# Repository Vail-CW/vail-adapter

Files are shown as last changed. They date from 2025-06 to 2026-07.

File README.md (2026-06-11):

# Vail Adapter: Morse Code Key / Paddle to USB

<p align="center">
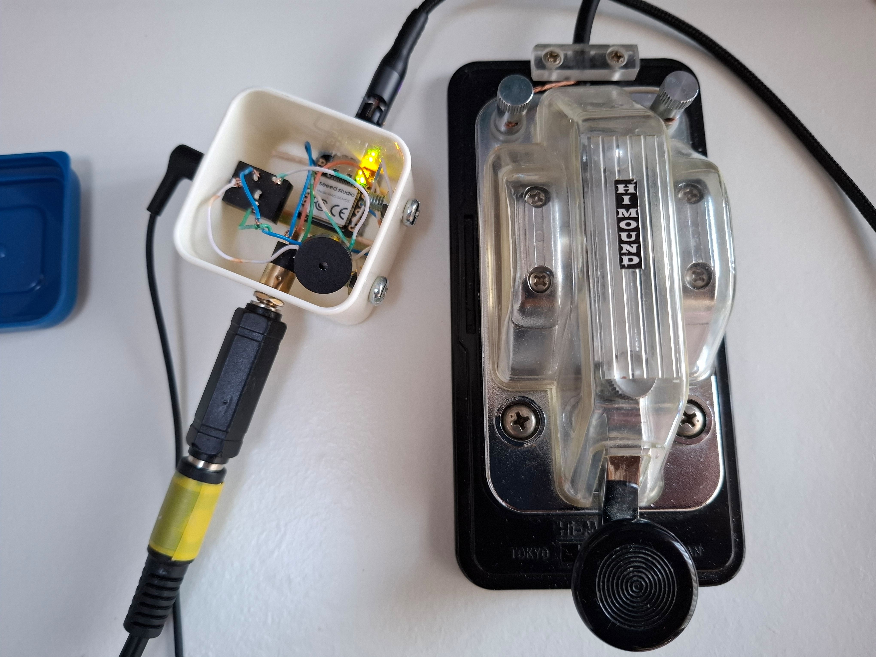
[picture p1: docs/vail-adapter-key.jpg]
Vail Adapter wired to a straight key
  
  &nbsp;&nbsp;
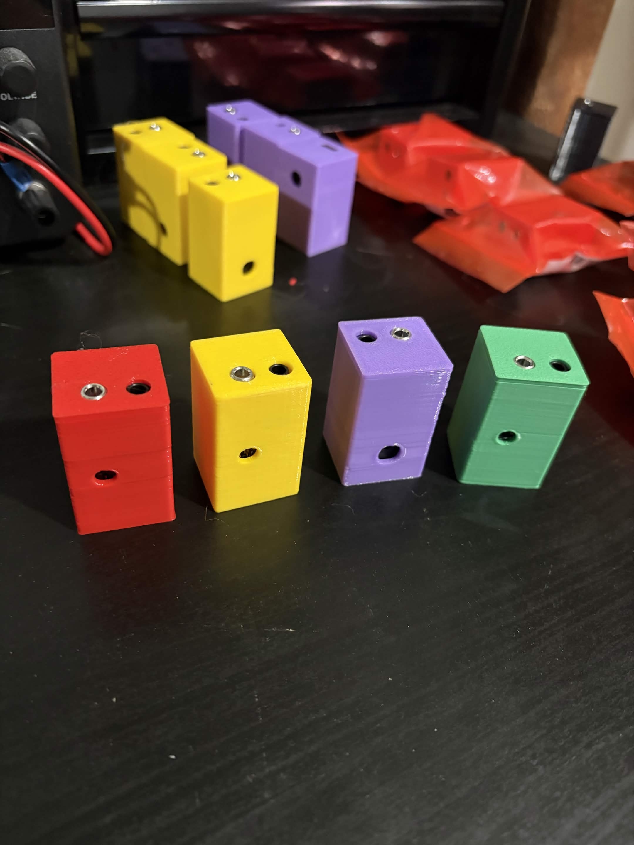
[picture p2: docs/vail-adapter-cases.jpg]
Vail Adapter 3D printed cases in several colors
  
</p>

The Vail Adapter is a small USB gadget that turns your Morse key or paddle into a USB device. It shows up as both a keyboard and a MIDI device, so it works with [Vail](https://vail.woozle.org/), [VBand](https://hamradio.solutions/vband/), and pretty much any CW software. The keyer logic and the sidetone run on the adapter itself, so there is no browser or operating system latency in your keying, even when you are running fast. It works on SAMD21 boards (the Seeed XIAO, the Adafruit QT Py, and the TRRS Trinkey), and there is an experimental build for the AVR Arduino Micro.

Here is a short video that shows what it can do: [Vail Adapter benefits](https://www.youtube.com/watch?v=XQ-mwdyLkOY) (4:46).

## What it does

* With Vail you can keep keying even when the Vail window is not focused, because Vail uses MIDI and MIDI does not care which window has focus
* Keyboard based apps like VBand work too, but their window has to stay focused, since keyboard presses only reach the window that is focused
* Runs all nine Vail keyer modes on the adapter, so you can key as fast as you want with no latency
* Has an optional sidetone generator, which helps with latency and lets you turn off your computer speaker
* Plays the received signal on the adapter so you can keep the computer quiet
* Stores CW memories: three slots, about 25 seconds each on SAMD21, and about 12 seconds each on the Arduino Micro
* Can key a radio directly through the optional radio output on the Advanced PCB
* Can be set up over MIDI for speed, tone, keyer type, and mode (see [MIDI integration](#midi-integration))
* Gets free firmware updates for life

## Where to get one

If you would rather not build your own, I sell them at [shop.ke9bos.com](https://shop.ke9bos.com). You can get a bare PCB, a full kit with everything you need, or a finished unit that is ready to plug in.

If you want to special order parts, place a bulk order, or you have a question about anything Vail related, email me at ke9bos@pigletradio.org and I will take care of you.

## Updating the firmware

You can flash the latest firmware right from your browser (Chrome, Edge, or Opera) at [update.vailadapter.com](https://update.vailadapter.com). Choose your board, pick a version, and follow the steps on the page. Every firmware version is posted on the [releases page](https://github.com/Vail-CW/vail-adapter/releases).

## First time setup

Once you have flashed an adapter, the first thing to do is run the getting started tool at [vailadapter.com/gettingstarted](https://vailadapter.com/gettingstarted). It walks you through getting set up and making sure everything is working.

The full manual is on the website at [vailadapter.com/manual](https://vailadapter.com/manual). It covers the buttons, the keyer modes, the memories, and the rest of the day to day use.

## Building your own

Step by step assembly guides for both boards are on the website at [vailadapter.com/assembly](https://vailadapter.com/assembly), and the PDFs are kept in this repo too: [Basic PCB v2](online-updater/assembly/BasicPCBV2.pdf) and [Advanced](online-updater/assembly/AdvancedAdapterAssemblyInstructions.pdf). If you would rather not source parts and solder, you can get a kit or a finished unit from [shop.ke9bos.com](https://shop.ke9bos.com).

The board designs (KiCad and gerbers) and the printable cases are in [hardware/](hardware/), organized by variant.

### Basic PCB (v2)

* Seeed Studio XIAO SAMD21 (from [Amazon](https://www.amazon.com/gp/product/B08CN5YSQF?smid=A2OY3Y9CEYQQ5W)) or an [Adafruit QT Py SAMD21](https://www.adafruit.com/product/4600)
* A buzzer speaker
* A [PCB mount TRS connector](https://a.co/d/bLaRwym)
* A [switched PCB mount aux jack](https://www.amazon.com/dp/B07WR748JS)

You can order the bare PCB from JLCPCB or PCBWAY yourself, or get a bare board, a kit, or an assembled unit from [shop.ke9bos.com](https://shop.ke9bos.com).

### Advanced PCB

The Advanced PCB does everything the Basic does and adds a radio output, so you can key a rig directly, along with capacitive touch points. It uses more parts than the Basic build:

* Seeed Studio XIAO SAMD21 or an Adafruit QT Py SAMD21
* A buzzer speaker
* The Advanced Vail Adapter PCB
* 1 switching aux jack and 2 standard aux jacks
* 2 transistors and 2 resistors, which drive the radio output
* 2 screw terminal PCB mounts
* 2 headers for the Arduino

The radio output parts are easy to get wrong when you buy them one at a time, so most people get the Advanced build as a kit or assembled from [shop.ke9bos.com](https://shop.ke9bos.com). The full build steps are in the [Advanced assembly guide](online-updater/assembly/AdvancedAdapterAssemblyInstructions.pdf).

### Without a PCB

* Seeed Studio XIAO SAMD21 (or an Adafruit QT Py SAMD21)
* A buzzer speaker
* A [panel mount aux jack](https://www.amazon.com/dp/B01C3RFHDC)

### Vail Lite, the USB stick version

* An [Adafruit TRRS Trinkey M0](https://www.adafruit.com/product/5954), which is a USB stick sized board with a TRRS jack built in
* A piezo buzzer, connected through the STEMMA QT connector
* It has no buttons, no capacitive touch, no headphone jack, and no radio output, so you change settings over MIDI
* Full instructions are in [TRRS_TRINKEY_BUILD.md](docs/TRRS_TRINKEY_BUILD.md)

### Arduino Micro (experimental)

This is a 5V AVR alternative to the SAMD21 boards. It is for DIY and breadboard builds only, and there is no PCB made for it.

* Wiring: D2 is Dit, D1 is Dah, D0 is the Straight Key, D10 is the Piezo, and GND is ground. There is a full walkthrough in [docs/advanced-install.md](docs/advanced-install.md).
* A few things it cannot do compared to the SAMD21 boards: no capacitive touch, no button menu, and no status LEDs. The CW memories are shorter at about 12 seconds each, and the radio output on A2 and A3 runs at 5V, so check that your radio can handle it or use a level shifter.
* Flashing is different too. It uses WebSerial with the AVR109 (Caterina) bootloader instead of UF2 drag and drop. Flash it at [update.vailadapter.com](https://update.vailadapter.com) by choosing DIY No PCB and then Arduino Micro in Chrome, Edge, or Opera, or run `arduino-cli upload --fqbn arduino:avr:micro`.

## Setting it up

* [Easy Setup](docs/easy-install.md)
* [Advanced Setup](docs/advanced-install.md)
* [See some that other people have built](https://github.com/Vail-CW/vail-adapter/wiki#cool-people-who-have-built-one)

The full manual is at [vailadapter.com/manual](https://vailadapter.com/manual).

## MIDI integration

The adapter is a standard USB MIDI device. Software can set the mode, the speed, the sidetone, and the keyer type, and it can read the keyed output as MIDI notes. The whole protocol, including the message types, the value ranges, and exactly how the firmware responds, is written up in [MIDI_INTEGRATION_SPEC.md](docs/MIDI_INTEGRATION_SPEC.md). If you are building something that talks to the adapter, follow that document closely, because I keep the existing MIDI commands the same on purpose. There is more about that just below.

## Contributing

I am glad to have help with this project. If you have a question, want parts, or want to talk through an idea, email me at ke9bos@pigletradio.org. If the adapter has been useful to you and you want to support more work on it, you can [buy me a coffee](https://buymeacoffee.com/ke9bos).

### Guidelines

The Vail Adapter has one job and it does it well. It is a simple, reliable, low latency bridge from a Morse key or paddle to USB. A lot of people, and a lot of outside tools, already count on the way it works today, so I review changes with that in mind. Here is what I ask:

1. Do not change the existing MIDI commands. The MIDI commands that are already there, for mode, speed, tone, keyer selection, and the dit, dah, and straight key notes the adapter sends, are something other tools and the Vail and VBand sites depend on. The commands, the value ranges, and the note numbers need to stay exactly as they are. I am happy to look at new MIDI commands, as long as they use messages that are not already being used and they do not change or interfere with anything that already works. If you add one, update the MIDI spec to match.

2. Keep it backward compatible. Do not break the things people already rely on, like the keyboard output (Dit is Left Control and Dah is Right Control), starting up in keyboard mode, saved settings, or the USB keyboard and MIDI interfaces. If you change how settings are stored, make sure the settings people already have still load.

3. Keep it fast. The reason this thing exists is lag free keying. Do not add anything that slows down the path from the paddle to the output. If a feature needs heavy work, do that work somewhere other than the keying loop.

4. Keep it focused. This is a key and paddle adapter. It does keying, keyer modes, sidetone, CW memories, and the optional radio output. Bigger ideas like a display, WiFi, logging, or training games belong on the Vail Summit, not here.

5. Add new hardware without disturbing the old. If you add support for a new board, put it behind a setting in config.h so the boards that already work keep behaving exactly the same. The Arduino Micro support is a good example of this.

6. Make sure every board still builds. A change should not fix one board by breaking another. Check that all of the configurations still compile before you send it.

7. Watch the limits of the chips. There is not a lot of room to spare, especially on the Arduino Micro. New features have to fit without using up the headroom on the boards that already work.

8. Do not change the defaults without a good reason. The default keyer, speed, tone, and startup mode are what people expect when they turn it on. Changing them catches people off guard.

9. Add to it rather than change it. When you can, add a new mode, command, or setting instead of changing how an existing one behaves.

10. Talk to me before any big change. For a large rewrite or a whole new feature, open an issue or send me an email first so we can make sure it fits where the project is going.

## License and credits

* License: MIT. See [LICENSE.md](LICENSE.md).
* Originally written by Neale Pickett. Currently maintained by Brett Hollifield, KE9BOS.
* Contact: ke9bos@pigletradio.org

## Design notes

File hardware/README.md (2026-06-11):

# Hardware

Board designs and printable cases for the Vail Adapter, organized by variant.
Each variant folder holds the PCB design and, where there is one, the matching
3D printable case.

- `basic-adapter/`
  - `pcb/` - KiCad project and gerbers for the Basic PCB
  - `case/` - printable case (STL) and Fusion 360 source (.f3d)
- `advanced-adapter/`
  - `pcb/` - KiCad project and gerbers for the Advanced PCB (adds radio output)
  - `case/` - printable case and Fusion 360 source
- `button-hat/`
  - `pcb/` - KiCad project and gerbers for the button hat add on

Order bare PCBs from JLCPCB or PCBWAY using the gerber zip in each `pcb/` folder,
or get a kit or a finished unit from [shop.ke9bos.com](https://shop.ke9bos.com).
Step by step assembly guides are at [vailadapter.com/assembly](https://vailadapter.com/assembly).

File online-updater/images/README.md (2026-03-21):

# Button Hat Modification Images

This directory contains images referenced by `button-hat-mod.html`.

## Images Included

### 1. `diagram.png`
- **Description:** QT Py SAMD21 pinout diagram
- **Purpose:** Reference diagram showing the location of pins A3 and A8
- **Content:** Arduino pin diagram for QT Py SAMD21

### 2. `1.jpg`
- **Description:** Example of completed button hat modification (view 1)
- **Purpose:** Show the jumper wire routing from A3 pad to A8 pin
- **Content:** Photo of actual solder job showing the modification

### 3. `2.jpg`
- **Description:** Example of completed button hat modification (view 2)
- **Purpose:** Alternative angle showing wire routing and solder quality
- **Content:** Photo of actual solder job from different angle

## Image Guidelines

- **Format:** JPEG (.jpg) recommended for photos
- **Resolution:** At least 1200px on the longest side for detail
- **Focus:** Clear, well-lit photos showing the modification details
- **Annotations:** Optional but helpful - add arrows or labels to highlight key areas

## Fallback Behavior

If images are not present, the guide page will display placeholder text explaining what the image should show. Users can still complete the modification using the text instructions.

## Adding Images

1. Copy your images to this directory
2. Ensure filenames match exactly: `qtpy-pinout.jpg`, `button-hat-mod-example1.jpg`, `button-hat-mod-example2.jpg`
3. Commit and push to update the GitHub Pages site

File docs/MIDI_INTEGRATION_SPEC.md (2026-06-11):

# Vail Adapter MIDI Integration Specification

## Overview

The Vail Adapter is an open-source Morse code keyer that provides both USB HID keyboard functionality and USB MIDI control. This document specifies how external applications can integrate with the MIDI portion of the adapter to control keyer behavior, tone generation, and timing parameters.

> All multi-byte examples below are raw MIDI bytes in hex, e.g. `B0 00 00`.

## Device Information

- **Device Type**: USB MIDI Class-Compliant Device
- **MIDI Channel**: 1 (Channel 0 in zero-indexed systems) — all status bytes are `B0/C0/90/80`
- **Vendor**: Open Source Hardware
- **Compatible with**: Any MIDI-capable application or DAW

## MIDI Message Types

The Vail Adapter responds to the following MIDI message types:

### Control Change Messages (0xBn)

#### CC0 - Mode Control
**Purpose**: Switch between Keyboard mode and MIDI mode

- **Message**: `B0 00 xx`
- **Values** (the value byte selects the mode by threshold, `value > 0x3F` = Keyboard):
  - `00-3F` (0-63): Enable **MIDI mode** (the adapter sends MIDI note events)
  - `40-7F` (64-127): Enable **Keyboard mode** (the adapter sends USB HID keyboard events)
- **Default**: Keyboard mode on startup
- **Examples**:
  - `B0 00 00` → enable MIDI mode
  - `B0 00 7F` → enable Keyboard mode

> Note: the mode is controlled **only** by CC0. Sending other MIDI messages
> (CC1/CC2, Program Change, Note On/Off) does **not** change the mode — issue a
> CC0 with a value of `00-3F` to put the adapter into MIDI mode first.

#### CC1 - Dit Duration (Speed Control)
**Purpose**: Control keying speed by setting dit duration

- **Message**: `B0 01 xx`
- **Formula**: Dit duration = `xx × 2` milliseconds; WPM = `1200 / dit_ms`
- **Range**: value `01`-`7F` → 2 ms to 254 ms (≈ 600 WPM down to ≈ 4.7 WPM)
- **Default**: value 50 (100 ms dit duration ≈ 12 WPM)
- **Example**: `B0 01 32` sets dit duration to 100 ms (~12 WPM)

#### CC2 - Sidetone Note
**Purpose**: Set the MIDI note number for the sidetone frequency

- **Message**: `B0 02 xx`
- **Range**: 0-127 (standard MIDI note numbers)
- **Default**: 69 (A4 = 440 Hz)
- **Tuning**: equal temperament
- **Example**: `B0 02 2D` sets sidetone to note 45 = A2 (110 Hz)

### Program Change Messages (0xCn)

#### Keyer Mode Selection
**Purpose**: Select the keyer algorithm/behavior

- **Message**: `C0 xx`
- **Keyer Types**:
  - `00`: Passthrough (manual control — routes paddle/key directly; in MIDI mode sends notes C#/D for dit/dah, C for a straight key)
  - `01`: Straight Key (cootie)
  - `02`: Bug (semi-automatic)
  - `03`: Electric Bug
  - `04`: Single Dot
  - `05`: Ultimatic
  - `06`: Plain Iambic
  - `07`: Iambic A
  - `08`: Iambic B
  - `09`: Keyahead
- **Default**: 8 (Iambic B) — the value written when the EEPROM is first initialized
- **Invalid values**: numbers outside `00-09` fall back to passthrough (0)

### Note On/Off Messages (0x9n/0x8n) — received by the adapter
**Purpose**: Manual sidetone generation (works like a standard MIDI synthesizer)

- **Note On**: `90 xx yy` (start playing note `xx`; velocity `yy` is accepted but ignored)
- **Note Off**: `80 xx yy` (stop playing note `xx`)
- **Range**: 0-127 (standard MIDI notes)
- **Behavior**: Drives the built-in buzzer only — it does not affect keyer logic. No tone is produced while the buzzer is disabled or while radio mode is active.

## MIDI Output — notes the adapter sends

When in **MIDI mode**, keying produces Note On (`90 nn 7F`) / Note Off (`80 nn 00`)
events on channel 1, where the note number `nn` is:

| Note number | Pitch | Sent for |
|---|---|---|
| `0` | C  | Straight key, and any element from keyer modes 1-9 (already-timed key-down) |
| `1` | C# | Dit (passthrough mode 0, or direct paddle routing) |
| `2` | D  | Dah (passthrough mode 0, or direct paddle routing) |

In practice, set the keyer to **Passthrough (PC 0)** when you want the host to
receive distinct dit (`1`/C#) and dah (`2`/D) events and do its own timing — this
is how the Vail web repeater drives the adapter. With any onboard keyer (PC 1-9),
the adapter performs the timing itself and emits note `0` (C) for each element.

## Integration Example

A sample sequence to configure the adapter:

```
# Enable MIDI mode
B0 00 00

# Set medium speed (120 ms dit = ~10 WPM)
B0 01 3C

# Set sidetone to middle C (C4, 261.6 Hz)
B0 02 3C

# Select Passthrough so the host receives dit/dah notes and does its own timing
C0 00
```

### Implementation Notes

1. **Mode switching**: The mode is set exclusively by CC0 (`00-3F` = MIDI, `40-7F` = Keyboard). The adapter does **not** auto-switch on other messages.
2. **Settings persistence**: Keyer type, dit duration, and sidetone note are saved to EEPROM and restored on power-up. (Output mode from CC0 is **not** persisted — the adapter always boots in Keyboard mode.)
3. **Real-time response**: All MIDI commands take effect immediately.
4. **Keyboard-mode output**: In Keyboard mode, dit sends Left Ctrl and dah sends Right Ctrl as USB HID key events.

## Technical Specifications

- **USB MIDI Class**: 1.0 compliant
- **Latency**: <1 ms for MIDI command processing
- **Concurrent Notes**: Single note playback (monophonic)
- **Power Requirements**: USB bus powered
- **Operating System**: Windows, macOS, Linux (class-compliant)

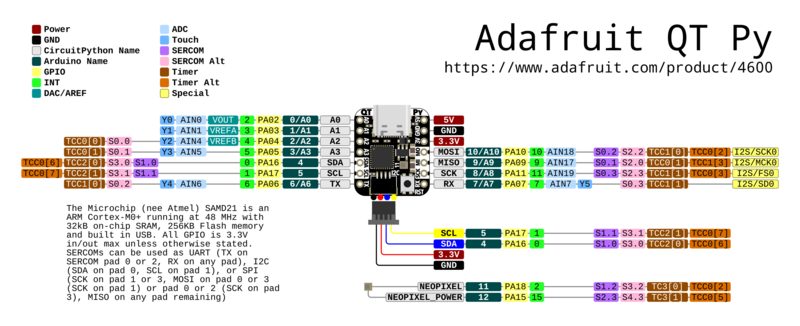
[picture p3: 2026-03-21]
online-updater/images/diagram.png

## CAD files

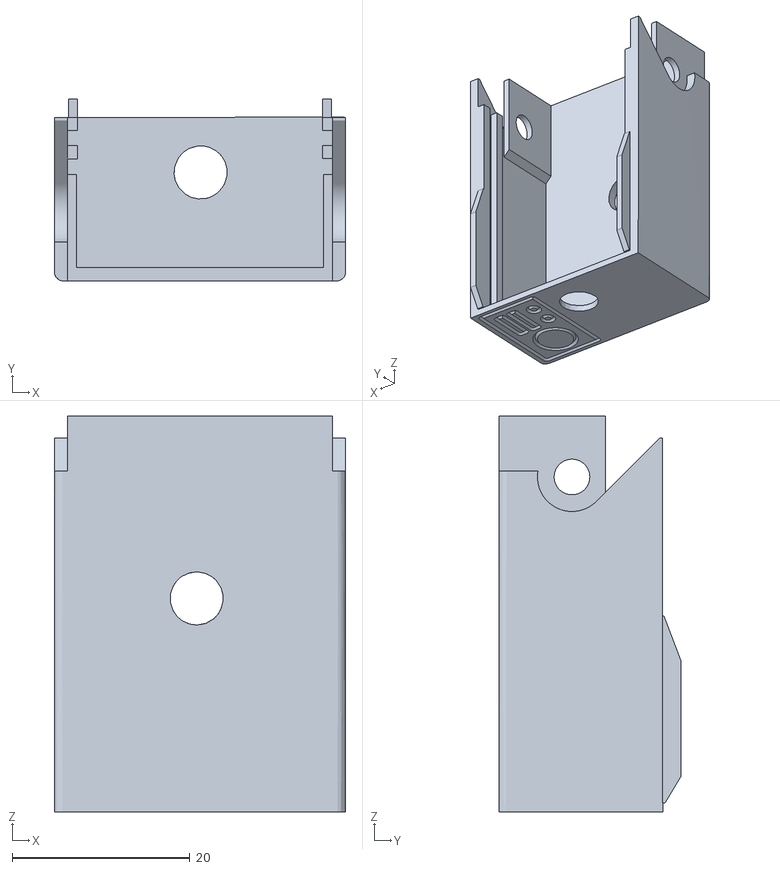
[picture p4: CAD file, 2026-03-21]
hardware/advanced-adapter/case/Advanced_W_Button_Cap.stl.stl
32.7 x 20.5 x 44.5

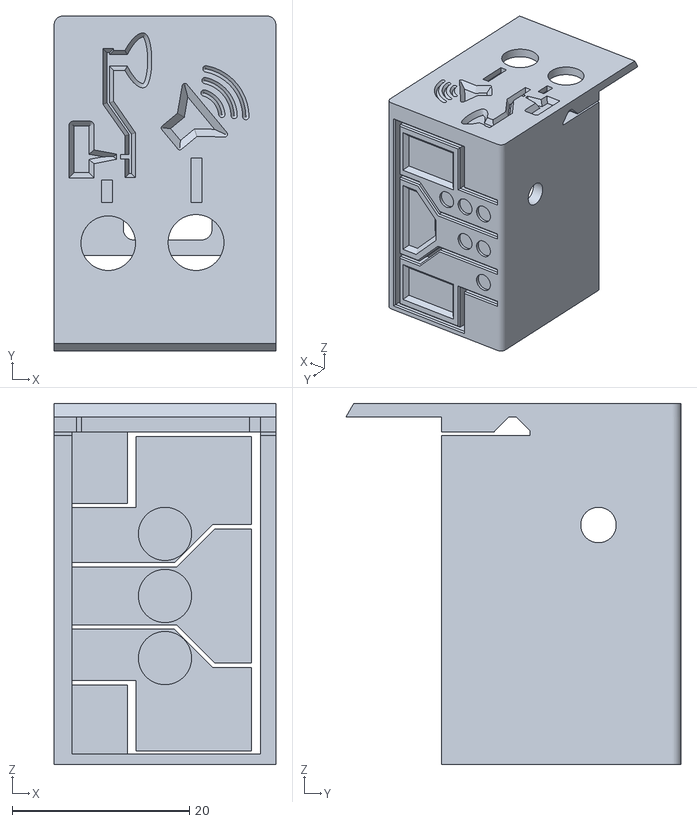
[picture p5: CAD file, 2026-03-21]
hardware/basic-adapter/case/BasicV2_W_Button_Case.stl
25.0 x 37.8 x 40.7

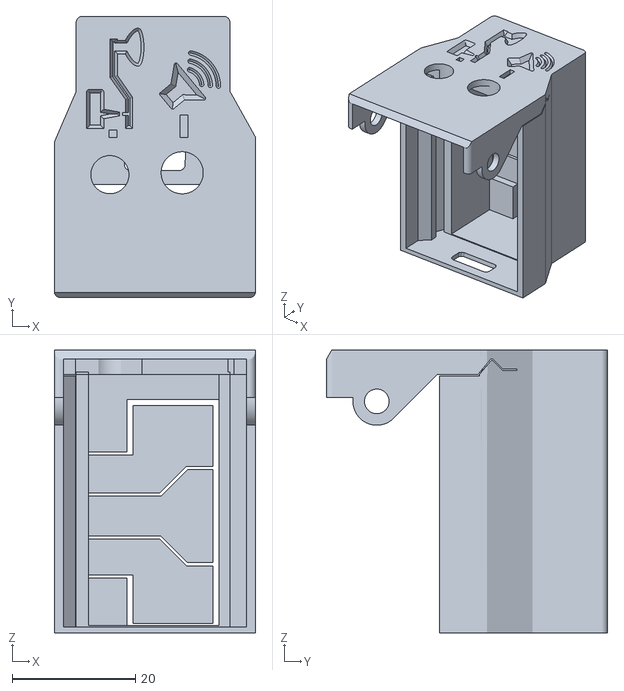
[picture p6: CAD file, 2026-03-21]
hardware/advanced-adapter/case/Advanced_W_Button_Case.stl
32.7 x 45.7 x 46.0

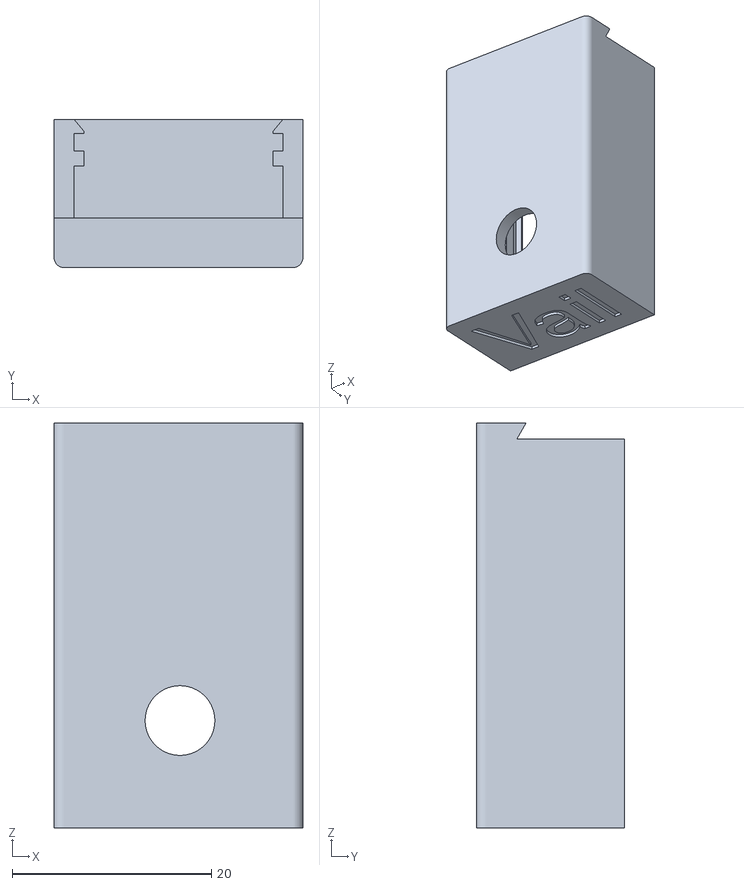
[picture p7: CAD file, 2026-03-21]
hardware/basic-adapter/case/BasicV2_W_Button_Cap.stl
25.0 x 14.9 x 40.7

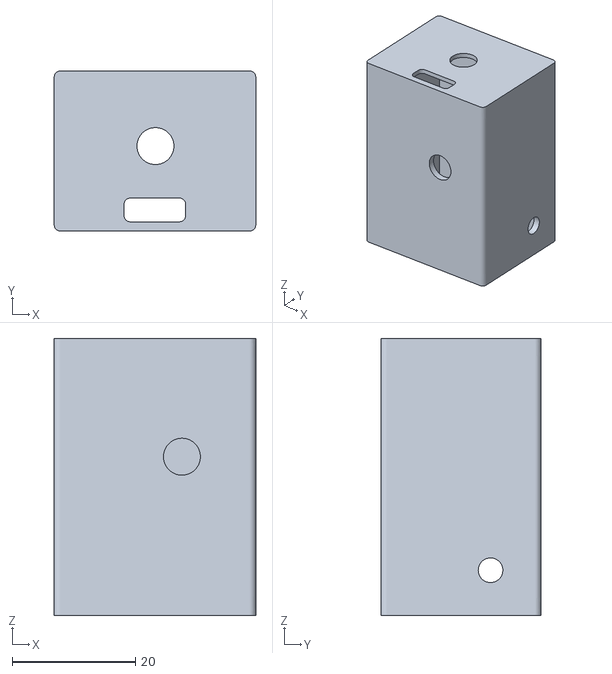
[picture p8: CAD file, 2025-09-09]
hardware/advanced-adapter/case/Advanced Case Body.stl
32.8 x 26.0 x 45.0

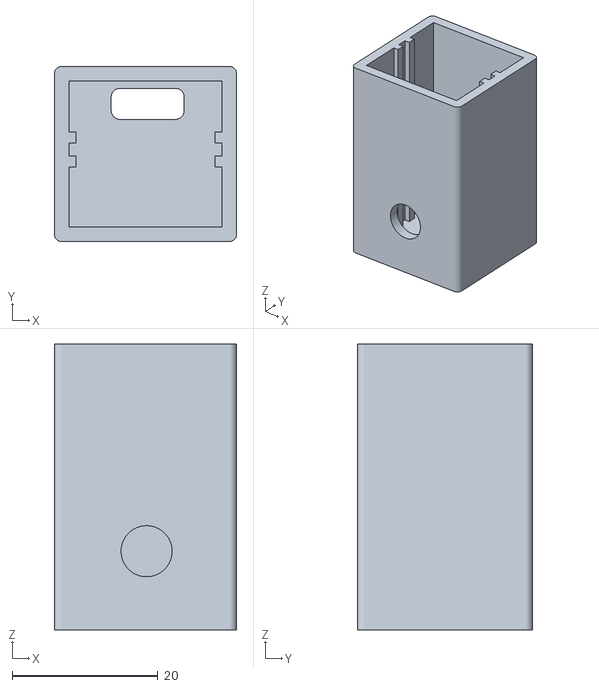
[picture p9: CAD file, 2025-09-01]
hardware/basic-adapter/case/up to date basic pcb case.stl
25.0 x 24.0 x 39.2

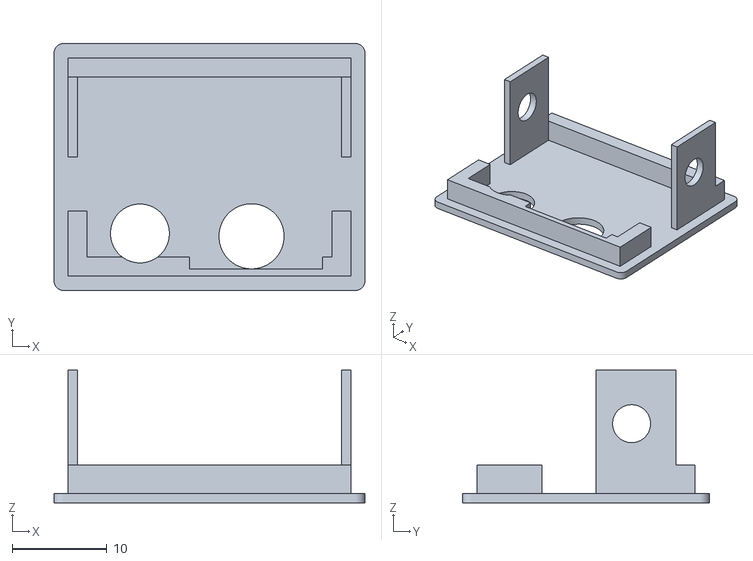
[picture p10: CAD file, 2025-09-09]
hardware/advanced-adapter/case/adv case lid.stl
32.8 x 26.0 x 14.0

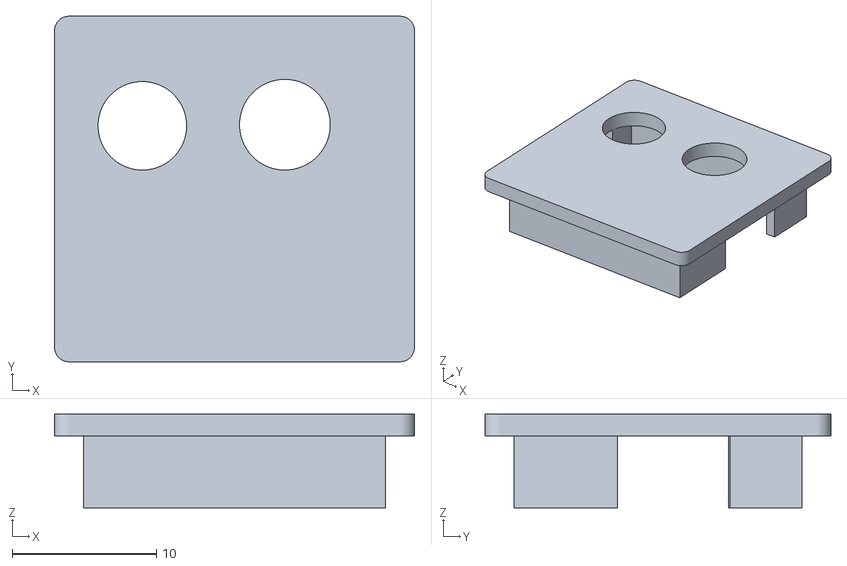
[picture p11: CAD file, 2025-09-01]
hardware/basic-adapter/case/up to date basic pcb lid.stl
25.0 x 24.0 x 6.50

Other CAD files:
hardware/basic-adapter/case/BasicV2_W_Button.f3d

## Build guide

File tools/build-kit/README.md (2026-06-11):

# Build kit

Compile the Vail Adapter firmware locally and get a `.uf2` (or `.hex` for the
Arduino Micro) for **every** hardware variation, in one command. This builds the
firmware source at the **repo root**, so what you flash always matches the code
in this checkout.

## Run it

From the repo root, or from this folder:

### Linux / macOS
```bash
chmod +x tools/build-kit/build.sh    # first time only
tools/build-kit/build.sh
```

### Windows
- Double-click `tools\build-kit\build.bat`, or
- From PowerShell:
  ```powershell
  powershell -NoProfile -ExecutionPolicy Bypass -File tools\build-kit\build.ps1
  ```

## What you get

Every variation is built into `tools/build-kit/uf2_output/`:

```
uf2_output/
├── xiao_basic_pcb_v1.uf2     qtpy_basic_pcb_v1.uf2
├── xiao_basic_pcb_v2.uf2     qtpy_basic_pcb_v2.uf2
├── xiao_advanced_pcb.uf2     qtpy_advanced_pcb.uf2
├── xiao_non_pcb.uf2          qtpy_non_pcb.uf2
├── trinkey_vail_adapter.uf2
└── arduino_micro.hex         (Arduino Micro is AVR -> .hex, not .uf2)
```

The script edits the repo's `config.h` to select each hardware target, then
**restores your original `config.h`** automatically when it finishes (even if a
build fails). You don't have to touch `config.h` yourself.

## Requirements

- **Internet** on the first run - it downloads arduino-cli (into
  `tools/build-kit/bin/`) plus the board cores (Seeed SAMD, Adafruit SAMD,
  Arduino AVR) and libraries, a few hundred MB. Later runs are fast and offline.
- **Python 3** - used only for the `.bin -> .uf2` step. Preinstalled on most
  Linux/macOS; on Windows install from python.org or the Microsoft Store.
- You do not need to install arduino-cli yourself; the script fetches a local
  copy if it isn't already on your PATH.

## Flash a build

1. Plug the board in with a data USB cable.
2. Double-tap the reset button - a removable drive appears (`XIAOBOOT`,
   `QTPYBOOT`, `ADAPTERBOOT`, ...).
3. Drag the matching `uf2_output/<board>.uf2` onto that drive.

The Arduino Micro doesn't use UF2 - flash `arduino_micro.hex` with
`arduino-cli upload` or a WebSerial/AVR109 flasher instead.

Firmware for releases is published as GitHub Release assets; this kit is for
building locally from source.

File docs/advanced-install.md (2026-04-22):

# Advanced Install

In the Arduino IDE, edit [vail-adapter.ino](../vail-adapter.ino) with the pins
you want to use on your device. 

You will need the MidiUSB and Keyboard libraries installed.
You can do this through the Library manager.

Then compile and upload the sketch.

## Works with no source code changes

* Seeeduino Xiao SAMD21
* Adafruit Qt Py SAMD21
* Arduino Micro (select the `ARDUINO_MICRO_BOARD` config — see below)

## Known to work with source code changes

* KeeYees Pro Micro
* Arduino Leonardo
* Arduino Zero
* Adafruit Trinket M0
* Adafruit GEMMA M0
* Adafruit Feather M0

## Arduino Micro — Notes and Build

The Arduino Micro is supported as an experimental DIY/breadboard-only target (there's no Micro PCB variant). It uses 5V logic instead of the SAMD21's 3.3V, and has a micro-USB connector.

### Build

1. In `config.h`, uncomment `#define ARDUINO_MICRO_BOARD` and comment out all other board configs.
2. Build with:
   ```
   arduino-cli compile --fqbn arduino:avr:micro --output-dir build_output --export-binaries .
   ```
3. Flash with:
   ```
   arduino-cli upload --fqbn arduino:avr:micro -p <PORT> build_output
   ```
   …or use the web updater at [vailadapter.com](https://vailadapter.com) (activate the 🧪 Test channel and pick **DIY No PCB → Arduino Micro** in the wizard — it speaks the Caterina/AVR109 protocol via WebSerial).

### Micro pinout & wiring

Full pinout diagram and datasheet: [docs.arduino.cc/hardware/micro](https://docs.arduino.cc/hardware/micro).

Required connections:

| Function | Micro pin | Notes |
|---|---|---|
| Ground | `GND` | Common for paddle/key, piezo, radio |
| Dit (paddle) | `D2` | Tie paddle dit contact to D2, ring it to GND through the switch |
| Dah (paddle) | `D1` | Same pattern as dit |
| Straight key | `D0` | For a straight key or mono-TRS jack tip |
| Piezo buzzer | `D10` → piezo `+`, `GND` → piezo `−` | Passive piezo; polarity doesn't matter for tone |
| Radio output dit (optional) | `A3` | **5V logic** — verify radio tolerance or use a level shifter/transistor |
| Radio output dah (optional) | `A2` | Same 5V caveat |

The internal pull-ups are enabled, so each input pin (D0/D1/D2) is HIGH when the contact is open and pulled LOW when the paddle/key closes. No external resistors needed on the paddle side.

### Using a 3.5mm TRS headphone jack (straight key or paddle)

Wire the jack exactly like the XIAO version, using the Micro's equivalent pins:

```
    o  --- D2  (tip   — dit, or straight-key contact)
   |_| --- D1  (ring  — dah)
   | | --- GND (sleeve)
   | |
```

For a simple mono straight key, wire only tip (`D0`) and sleeve (`GND`).

### Entering the bootloader

The web updater handles this automatically (1200-baud touch), but if you need to do it manually:

- **Double-tap the reset button** on the Micro within ~1 second. A new COM port will appear for ~8 seconds — that's the Caterina bootloader port.

### Micro limitations

* **No capacitive touch** — ATmega32U4 lacks the FreeTouch hardware. All paddle/key inputs must use physical switches.
* **No button menu** — the resistor-ladder menu is SAMD-only. Change settings via MIDI (vailmorse.com) instead.
* **No LED status indicators** — the onboard LED is not driven by the firmware (RAM is tight; skipped for the AVR port).
* **CW memory** — 3 slots × ~12 seconds each (vs. 25 seconds on SAMD21), due to the 1024-byte EEPROM and 2.5 KB RAM budget.
* **5V radio output** — the optional radio pins swing to 5V, not 3.3V. Verify your radio's keying line can accept 5V, or use a transistor/level shifter.
* **Flashing** — no UF2 drag-and-drop. Use the web updater's test channel, Arduino IDE, or `arduino-cli upload`.

## Will Not Work!

The RP2040 chip will not work, because it lacks a USB MCU,
needed by the MIDIUSB library. 
I'm listing specific devices here
in the hopes that seeing them crossed out will prevent people from
making a purchasing mistake!

* ~~Seeeduino Xiao RP2040~~ Will not work!
* ~~Adafruit Qt Pi RP2040~~ Will not work!
* ~~Any RP2040 Device~~ Will not work!

# Advanced Wiring

XIAO Pinout

* GND: Ground
* D2: Dit
* D1: Dah
* D0: Straight Key
* D10: Speaker or Passive piezo buzzer
* A6: Capacative Dit
* A7: Capacative Dah
* A8: Capacative Straight Key

## Using a headphone jack

You can wire a headphone jack up to GND, D1, and D2.
GND should be the sleeve, D1 the ring, and D2 the tip.

     o  --- D2 (tip, dit)
    |_| --- D1 (ring, dah)
    | | --- GND (sleeve)
    | |

## Sidetone generator

If you connect a buzzer or speaker to pin 10 on one leg,
and ground on the other,
the adapter will beep when you press the straight key.

This will help a lot if there is a noticeable delay between when you press the key
and when your computer starts making a local beeping sound.

If you feel like no matter what you do,
you're always getting DAH with your straight key,
you should try this.

## Capacative Touch

The adapter works as a capacative touch sensor,
like a touch lamp.

You might wire these pins to screws or conductive pads. 
These can be used instead of, or in addition to, the normal pins D0, D1, and D2.

You do not need a ground wire with capacative touch!

* Pin A6: Dit capacative touch
* Pin A7: Dah capacative touch
* Pin A8: Straight key capacative touch

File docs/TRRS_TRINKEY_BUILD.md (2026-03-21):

# TRRS Trinkey Build Guide

## Overview

The Adafruit TRRS Trinkey is a tiny USB key-sized SAMD21 board with a built-in TRRS (3.5mm audio) jack, making it ideal for a minimal Vail adapter build.

## Hardware Setup

### TRRS Jack Connections

The Trinkey's TRRS jack pins are mapped as follows:

- **Tip (Pin 0)** → DIT input
- **Ring 1 (Pin 2)** → DAH input
- **Ring 2 (Pin 4)** → Not used
- **Sleeve (Pin 5)** → Ground

**For paddle operation:**
- Use a stereo (TRS) cable from your paddle
- Tip connects to dit paddle contact
- Ring connects to dah paddle contact
- Sleeve is ground

**For straight key operation:**
- Use a mono (TS) cable from your straight key
- Tip connects to key contact
- Sleeve is ground
- The firmware will use the dit input (Pin 0) for straight key

### Buzzer Connection

Connect a piezo buzzer through the STEMMA QT connector:

- **Positive (+)** → SCL (Pin 9 / PA09)
- **Negative (-)** → GND

The STEMMA QT connector has four pins (in order):
1. GND (Black wire)
2. 3V (Red wire)
3. SDA (Blue wire / Pin 8)
4. SCL (Yellow wire / Pin 9)

Connect your buzzer between **GND (pin 1)** and **SCL (pin 4)**.

## Software Setup

### Prerequisites

Install arduino-cli and configure it for Adafruit boards:

```bash
arduino-cli config init
arduino-cli config add board_manager.additional_urls https://adafruit.github.io/arduino-board-index/package_adafruit_index.json
arduino-cli core update-index
arduino-cli core install adafruit:samd
```

Install required libraries:

```bash
arduino-cli lib install MIDIUSB "Adafruit FreeTouch Library" FlashStorage_SAMD Keyboard
```

### Configuration

1. Edit `config.h` and ensure **only** the TRRS_TRINKEY configuration is enabled:

```cpp
// #define V1_Basic_PCB
// #define V2_Basic_PCB
// #define Advanced_PCB
// #define NO_PCB_GITHUB_SPECS
#define TRRS_TRINKEY
```

2. All other configurations should be commented out.

### Building

Build the firmware with the Trinkey M0 board profile:

```bash
arduino-cli compile --fqbn adafruit:samd:adafruit_trinkey_m0 --output-dir build_output --export-binaries .
```

### Converting to UF2 (for drag-and-drop flashing)

Convert the .bin file to .uf2 format:

```bash
python uf2conv.py -c -f 0x68ED2B88 -b 0x2000 build_output/*.bin -o trinkey_vail_adapter.uf2
```

The family ID `0x68ED2B88` is for SAMD21 devices.

### Flashing

1. **Enter bootloader mode:**
   - Press the reset button on the Trinkey **twice quickly**
   - The NeoPixel LED will turn green/blue and a `TRINKETBOOT` drive will appear

2. **Flash the firmware:**
   - Drag `trinkey_vail_adapter.uf2` onto the `TRINKETBOOT` drive
   - The board will automatically reset and run the new firmware

## Pin Configuration Summary

| Function | Pin | Notes |
|---|-----|---|
| DIT Input | 0 (TIP) | TRRS tip contact |
| DAH Input | 2 (RING1) | TRRS ring 1 contact |
| KEY Input | 0 (TIP) | Same as DIT for straight key mode |
| Piezo Buzzer | 9 (SCL) | Via STEMMA QT connector |
| NeoPixel LED | 1 | Built-in status LED |

## Limitations

**No Button Menu:**
The Trinkey has no physical buttons, so the button menu system is not available. Settings must be changed via:
- MIDI control messages (CC0, CC1, CC2, PC)
- Modifying default values in code before building

**No Capacitive Touch:**
The Trinkey does not have capacitive touch capability.

**No Radio Output:**
This configuration does not include radio keying output pins.

## Default Settings

When flashed with default firmware:
- **Keyer Mode:** Iambic B (mode 8)
- **Speed:** 20 WPM (100ms dit duration)
- **Sidetone:** A4 (MIDI note 69, 440 Hz)
- **Output Mode:** USB HID Keyboard

## MIDI Control

To change settings without buttons, use MIDI control messages:

- **CC0** (value 0-1): Switch between keyboard (0) and MIDI (1) output mode
- **CC1** (value 10-200): Set dit duration (value × 2 milliseconds)
  - Example: Value 50 = 100ms dit = 20 WPM
- **CC2** (value 43-85): Set sidetone frequency (MIDI note number)
  - Example: 69 = A4 = 440 Hz
- **Program Change (PC)** (value 0-9): Select keyer mode
  - 0 = Passthrough
  - 1 = Straight Key
  - 2 = Bug
  - 3 = ElBug
  - 4 = Single Dot
  - 5 = Ultimatic
  - 6 = Plain
  - 7 = Iambic A
  - 8 = Iambic B
  - 9 = Keyahead

## Testing

After flashing:

1. **Test buzzer:** Power on the Trinkey - it should play "VAIL" in Morse code
2. **Test paddle/key:** Plug in your paddle/key cable and tap the contacts
3. **Test keyboard output:** Open a text editor and verify Ctrl key presses
4. **Test MIDI:** Send MIDI commands to verify mode switching and settings

## Board Information

- **MCU:** ATSAMD21E18 (32-bit Cortex M0+)
- **Clock:** 48 MHz
- **Flash:** 256 KB
- **RAM:** 32 KB
- **USB:** Native USB HID + MIDI
- **Board Package:** `adafruit:samd:adafruit_trinkey_m0`
- **Bootloader:** UF2 (double-tap reset to enter)

## Troubleshooting

**Trinkey not recognized:**
- Try a different USB port or cable
- Ensure the cable supports data, not just power

**No bootloader drive appears:**
- Reset timing is critical - try the double-tap slower or faster
- Try unplugging and re-plugging while holding reset

**Buzzer not working:**
- Verify connections to GND and SCL (pin 9) on STEMMA QT
- Check buzzer polarity (some piezo buzzers are polarized)
- Test with a multimeter in continuity mode

**No keyboard output:**
- Check that paddle cable is properly inserted
- Try switching keyer modes via MIDI
- Verify the device shows up as a USB keyboard in system settings

## References

- [Adafruit TRRS Trinkey Product Page](https://www.adafruit.com/product/5954)
- [Adafruit TRRS Trinkey Pinout Guide](https://learn.adafruit.com/adafruit-trrs-trinkey/pinouts)
- [Main Vail Adapter Documentation](README.md)
- [MIDI Integration Spec](MIDI_INTEGRATION_SPEC.md)

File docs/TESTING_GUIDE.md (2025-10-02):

# Vail Adapter Firmware Update Website - Manual Testing Guide

This guide outlines the steps to manually test the functionality and user interface of the Vail Adapter Firmware Update website (`index.html`).

**Last Updated:** YYYY-MM-DD (Update this as needed)
**Tester:** ____________________
**Browser(s) Tested:** ____________________ (e.g., Chrome vXX, Firefox vYY, Edge vZZ)
**Operating System:** ____________________

---

## I. Visual Inspection and Basic UI

**Objective:** Verify the initial page load, visual appearance, and responsiveness.

| Step | Action | Expected Result | Actual Result (Pass/Fail) & Notes |
|---|---|---|---|
| 1 | Open `index.html` in a modern web browser (e.g., Chrome, Firefox, Edge). | Page loads successfully. | |
| 2 | Check the browser tab/window title. | Title is "Vail Adapter Firmware Update". | |
| 3 | Look at the main heading on the page. | Main heading "Vail Adapter Firmware Update" is displayed prominently. | |
| 4 | Read the introductory paragraph below the main heading. | The paragraph clearly explains the purpose of the page. | |
| 5 | Verify the presence and titles of all six step sections. | All six sections are displayed in order with the following headings: <br>1. "Step 1: Choose Vail Adapter version"<br>2. "Step 2: Plug in Vail Adapter"<br>3. "Step 3: Enter Boot Mode"<br>4. "Step 4: Download UF2 File"<br>5. "Step 5: Drag and Drop UF2 File"<br>6. "Step 6: Finalize Update" | |
| 6 | Evaluate overall styling and readability. | - Font is clear and easy to read.<br>- Color scheme is consistent and visually appealing.<br>- Content is generally centered and well-spaced within a container.<br>- Sections are visually distinct (e.g., borders, background). | |
| 7 | Resize the browser window (from desktop width down to mobile width). | - Layout adjusts to smaller screen sizes without breaking.<br>- Text remains readable and does not overflow.<br>- Buttons and radio buttons are still usable and appropriately sized. | |

---

## II. Step 1: Choose Vail Adapter Version

**Objective:** Verify the functionality of the adapter version selection.

| Step | Action | Expected Result | Actual Result (Pass/Fail) & Notes |
|---|---|---|---|
| 1 | Examine the radio buttons in "Step 1". | Four radio button options are present with labels: "Non PCB/Basic", "Basic PCB V1", "Basic PCB V2", "Advanced PCB". | |
| 2 | Click on "Non PCB/Basic". | "Non PCB/Basic" is selected. | |
| 3 | Click on "Basic PCB V1". | "Basic PCB V1" is selected, and "Non PCB/Basic" becomes unselected. | |
| 4 | Click on "Basic PCB V2". | "Basic PCB V2" is selected, and "Basic PCB V1" becomes unselected. | |
| 5 | Click on "Advanced PCB". | "Advanced PCB" is selected, and "Basic PCB V2" becomes unselected. | |
| 6 | Verify label association. | Clicking on a label selects the corresponding radio button. | |

---

**III. Step 3: Press this button to enter boot mode (WebSerial Functionality)**

*Note: This requires a compatible SAMD21 device (Xiao SAMD21 or Adafruit QT Py SAMD21) that is NOT yet in bootloader mode. Ensure you are using a WebSerial compatible browser (e.g., Chrome, Edge).*

1.  **Prepare for Testing:**
    *   Open `index.html` in your WebSerial-compatible browser.
    *   Connect your SAMD21 device to the computer via USB.
    *   Open the browser's developer console (F12) and select the "Console" tab to monitor any background errors.
    *   Locate the "Activity Log:" area within Step 3 on the webpage. This will show specific messages from the script.

2.  **Initiate Boot Mode:**
    *   Click the "Press to Enter Boot Mode" button.
    *   Your browser should display a prompt asking you to select a serial port.
    *   Choose the serial port corresponding to your connected SAMD21 device. (The name might vary, e.g., "Adafruit QT Py SAMD21", "Arduino Zero", "USB Serial Device", etc.).
    *   Click "Connect" (or the equivalent button in the browser prompt).

3.  **Observe the Process:**
    *   **Activity Log on Webpage:** Watch the messages appearing in the "Activity Log:". You should see:
        *   "Attempting to trigger bootloader via WebSerial..."
        *   "Requesting serial port selection..."
        *   "Port selected."
        *   "Attempting 1200bps touch..."
        *   "Port opened at 1200bps."
        *   "Port closed after 1200bps touch."
        *   "SUCCESS: Bootloader mode command sent! ..."
    *   **Browser Console:** Check for any errors if the process doesn't complete as expected.
    *   **Device Behavior:** Your SAMD21 device should disconnect from the system (the serial port will disappear) and then, after a few seconds, reconnect.
    *   **New Drive:** After successful reconnection, a new storage drive should appear on your computer (e.g., "QTPYBOOT", "XIAOBOOT", "ADAPTERBOOT"). This indicates the device is in bootloader mode.

4.  **Test Error Conditions / Edge Cases:**
    *   **Cancel Port Selection:** Click the "Press to Enter Boot Mode" button, but click "Cancel" (or close) the browser's serial port selection prompt.
        *   Verify: The "Activity Log" should show an error message (e.g., "NotFoundError: User cancelled the port selection dialog." or similar). The operation should stop gracefully. An alert might also appear.
    *   **No Compatible Device Connected:** Disconnect your SAMD21 device. Click the "Press to Enter Boot Mode" button.
        *   Verify: The browser prompt might show no devices, or the script might log an error in the "Activity Log" if no port with the specified VIDs is found (e.g., "NotFoundError: No port selected by the user." or similar). An alert might also appear.
    *   **Device Already in Bootloader Mode:** If the device is already in bootloader mode (i.e., the drive is visible), this process might not work as expected or might try to connect to the bootloader serial port. Note the behavior. (Ideally, the user does this step when the device is running application code). The "Activity Log" might show messages, but the device won't reset.

**Troubleshooting "Error: WebSerial API not supported..."**
*   Ensure you are using a modern browser that supports WebSerial (e.g., Chrome version 78 or later, Edge version 79 or later). Firefox does not support WebSerial by default.

**Troubleshooting General Connection Issues:**
*   **Check Cables/Connections:** Ensure your USB cable is a data cable (not just charging) and is securely connected.
*   **Try Different USB Port:** Sometimes, specific USB ports can be problematic.
*   **Conflicting Software:** While WebSerial is generally better at sharing than WebUSB, ensure no other application (like Arduino IDE's serial monitor) is actively holding the *exact same serial port* open. The 1200bps trick often involves the OS temporarily losing the port, so conflicts are less common *during* the baud rate change itself, but initial connection can be an issue.
*   **Device Drivers:** Ensure your OS has the necessary drivers for the SAMD21's serial port (usually automatic on Windows 10/11, macOS, Linux).

---

## IV. Step 4: Download UF2 File

**Objective:** Verify the download button's state changes and file download functionality.

| Step | Action | Expected Result | Actual Result (Pass/Fail) & Notes |
|---|---|---|---|
| 1 | Observe the "Download UF2 File" button in "Step 4" on page load. | The button is initially disabled (e.g., greyed out, not clickable) and its text is "Download UF2 File". Clicking it might show an alert to select a version first. | |
| 2 | Go to "Step 1" and select the "Non PCB/Basic" radio button. | "Non PCB/Basic" is selected. | |
| 3 | Re-observe the button in "Step 4". | The button becomes enabled. Its text updates to "Download non_pcb_basic.uf2". | |
| 4 | Click the now enabled "Download non_pcb_basic.uf2" button. | A file download initiates. The suggested filename is `non_pcb_basic.uf2`. (Content will be placeholder text). | |
| 5 | Go to "Step 1" and select the "Basic PCB V1" radio button. | "Basic PCB V1" is selected. | |
| 6 | Re-observe the button in "Step 4". | The button remains enabled. Its text updates to "Download basic_pcb_v1.uf2". | |
| 7 | Click the "Download basic_pcb_v1.uf2" button. | A file download initiates. The suggested filename is `basic_pcb_v1.uf2`. | |
| 8 | Repeat steps 5-7 for "Basic PCB V2" and "Advanced PCB". | - Button text updates correctly for "Basic PCB V2" (to `basic_pcb_v2.uf2`).<br>- Button text updates correctly for "Advanced PCB" (to `advanced_pcb.uf2`).<br>- Downloads initiate with correct filenames. | |
| 9 | (If applicable) Refresh the page or select no radio button. | The download button should return to its disabled state and default text. | |

---

## V. Step 5: Drag and Drop UF2 File Instructions

**Objective:** Verify the clarity and accuracy of the UF2 file transfer instructions.

| Step | Action | Expected Result | Actual Result (Pass/Fail) & Notes |
|---|---|---|---|
| 1 | Read through all instructions in "Step 5". | - Instructions are clear, grammatically correct, and easy for a non-technical user to follow.<br>- Steps correctly describe opening a file explorer, finding the downloaded UF2, identifying the bootloader drive (e.g., "ADAPTERBOOT", "QTPYBOOT"), and the drag-and-drop action.<br>- Mentions LED activity and drive auto-ejecting. | |
| 2 | Check for any ambiguities or missing information. | All necessary information for this step is present. | |

---

## VI. Step 6: Finalize Update Instructions

**Objective:** Verify the clarity and accuracy of the finalization steps.

| Step | Action | Expected Result | Actual Result (Pass/Fail) & Notes |
|---|---|---|---|
| 1 | Read through all instructions in "Step 6". | - Instructions are clear, grammatically correct, and easy to follow.<br>- Steps correctly describe waiting, unplugging the adapter, and plugging it back in. | |
| 2 | Check for any ambiguities or missing information. | All necessary information for concluding the update process is present. | |

---

## VII. Console and Activity Log Checks

**Objective:** Identify any errors or warnings in the browser's developer console and the on-page Activity Log.

| Step | Action | Expected Result | Actual Result (Pass/Fail) & Notes |
|---|---|---|---|
| 1 | Open the browser's developer console (F12). | Console opens. | |
| 2 | Simultaneously monitor the "Activity Log:" area within Step 3 on the webpage. | The "Activity Log:" area is visible. | |
| 3 | During all steps, but *especially during Step 3 (Enter Boot Mode)*, observe both the browser console and the webpage's Activity Log for: | - Any error messages or warnings.<br>- Successful status messages being logged as expected in both locations (though Activity Log will be more specific to WebSerial steps).<br>- Ensure the messages in the Activity Log match the actions being performed. | |

---

**Overall Test Summary & Additional Notes:**

(Space for general comments, issues not covered above, or overall impression)

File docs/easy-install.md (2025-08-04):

# Easy Installation

1. Get a Seeeduino XIAO SAMD21
2. Download the most recent XIAO SAMD21 firmware from
[releases](https://github.com/nealey/vail-adapter/releases)
3. [Enter bootloader mode](https://wiki.seeedstudio.com/Seeeduino-XIAO/#enter-bootloader-mode)
4. Copy the firmware onto the XIAO SAMD21

[Wideo walkthrough of firmware upload](https://www.youtube.com/watch?v=IgOdkUe5SMY) (3:07)

If you would like to use a different microcontroller,
see the [advanced install instructions](advanced-install.md).

# Wiring

XIAO Pinout

* GND: Ground (usually in the middle of the paddle)
* Pin D2: Dit (usually left paddle)
* Pin D1: Dah (usually right paddle)

If you'd like to wire up a TRS (headphone) jack;
or take advantage of some of the adapters other features,
such as dedicated straight key, sidetone generation,
or capacative touch,
see the [advanced install instructions](advanced-install.md).

There is a Vail Discord run by Vail user K6JSC.
https://discord.gg/GBzj8cBat7

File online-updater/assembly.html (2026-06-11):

# Assembly Instructions

Click to download Basic PCB v2 DIY Kit Assembly Instructions

Click to download Advanced Vail Adapter Assembly Instructions

Back to Home

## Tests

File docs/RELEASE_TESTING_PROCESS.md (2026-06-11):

# Release Testing Process

This document describes how to use GitHub Issues for collaborative release testing of Vail Adapter firmware.

## Overview

Before releasing new firmware to users, we use a **two-tier GitHub Issue system** to coordinate testing across all 8 hardware configurations:

1. **Parent "Overview" Issue** - Tracks overall release progress, links to all hardware-specific issues
2. **Hardware-Specific Issues** - One issue per hardware config (XIAO/QT Py × 4 PCB versions) with detailed test checklists

This ensures quality testing across all hardware variants and catches configuration-specific issues before they reach end users.

## For Release Managers

### Creating Release Testing Issues

**🚀 Automated (Recommended):**

Use the GitHub Actions workflow to create all 9 issues automatically:

1. Go to **Actions** tab → **"Create Release Testing Issues"** → **"Run workflow"**
2. Fill in: version, build date, target date, and what's new
3. Click **"Run workflow"** - wait 10-30 seconds
4. Done! All 9 issues created and linked together

---

**📝 Manual (Alternative):**

If you prefer to create issues manually or the workflow is unavailable:

**Step 1: Create the Parent Overview Issue**

1. Go to your GitHub repository's Issues tab
2. Click "New Issue"
3. Select the **"Release Testing Overview (Parent Issue)"** template
4. Fill in the version number (e.g., "Release Testing: v2.1.0 - Overview")
5. Update the firmware build date and target release date
6. Fill in the "What's New in This Version" section
7. Create the issue - note the issue number (e.g., #42)

**Step 2: Create Hardware-Specific Testing Issues**

For each of the 8 hardware configurations, create a separate issue:

1. Click "New Issue" again
2. Select the **"Release Testing - Hardware Config"** template
3. Update the title with board and PCB version:
   - "Release Testing v2.1.0 - XIAO Non-PCB"
   - "Release Testing v2.1.0 - XIAO Basic V1"
   - "Release Testing v2.1.0 - XIAO Basic V2"
   - "Release Testing v2.1.0 - XIAO Advanced"
   - "Release Testing v2.1.0 - QT Py Non-PCB"
   - "Release Testing v2.1.0 - QT Py Basic V1"
   - "Release Testing v2.1.0 - QT Py Basic V2"
   - "Release Testing v2.1.0 - QT Py Advanced"
4. Fill in the board type and PCB version checkboxes
5. Link back to the parent issue (replace #___ with parent issue number)
6. Create the issue

**Step 3: Link Hardware Issues to Parent**

1. Go back to the parent overview issue
2. Edit the issue description
3. Add the issue numbers for each hardware config in the tracking table
4. Assign testers to specific hardware configurations (if known)

### Managing the Testing Process

1. **Assign testers** - Assign each hardware-specific issue to someone with that hardware
2. **Monitor progress** - Check the parent issue to see overall status at a glance
3. **Review hardware issues** - Click into individual hardware issues to see detailed test results
4. **Track coverage** - Update the parent issue's hardware tracking table as configs complete
5. **Address issues** - If critical bugs are found, link them in the parent issue's "Critical Issues" section
6. **Make go/no-go decision** - Once minimum requirements are met (2+ configs tested), decide whether to release

### Minimum Release Requirements

Before releasing, ensure:
- ✅ At least **2 different hardware configurations** fully tested and passing
- ✅ At least **2 different people** have signed off
- ✅ No **critical failures** reported in any hardware-specific issue
- ✅ CI/CD build completed successfully for all 8 configs
- ✅ `online-updater/index.html` updated with release notes

**Ideal Release Requirements:**
- 🎯 At least **4 different hardware configurations** tested (ideally mix of XIAO/QT Py and PCB versions)
- 🎯 Both XIAO and QT Py tested (at least one config each)
- 🎯 At least one Advanced PCB tested (for radio output features)

### After Successful Testing

1. Check off the "Pre-Release Checklist" items in the parent overview issue
2. Update the "Testing Progress Summary" section
3. Mark the parent issue status as "Ready for Release"
4. Create the GitHub release with all 8 firmware files
5. Close all hardware-specific testing issues
6. Close the parent overview issue
7. Announce the release

## For Testers

### How to Test a Release

1. **Find the parent issue** - Look for "Release Testing: v[VERSION] - Overview"
2. **Choose your hardware** - Find the hardware-specific issue that matches your configuration
3. **Claim the issue** - Comment that you're testing this config and add your name to the "Primary Tester" field
4. **Download firmware** - Get the appropriate UF2 file from the GitHub Release for the version (attached as a release asset)
5. **Run through tests** - Check off items in the hardware-specific issue as you test them
6. **Report issues** - Add detailed bug reports in the "Issues Found" section
7. **Sign off** - Check the final "Tester Sign-Off" boxes when complete
8. **Update parent issue** - Comment on the parent issue that your hardware config is complete

### Working with Hardware-Specific Issues

Each hardware config has its own dedicated issue with a comprehensive test checklist organized by category:

- **Core Functionality** - Basic firmware update and operation
- **Keyer Modes** - All 10 keyer modes (passthrough, straight, bug, iambic, etc.)
- **Input Hardware** - Physical and capacitive touch inputs
- **USB Output** - Keyboard and MIDI modes
- **Audio/Sidetone** - Buzzer functionality and control
- **Speed Control** - WPM adjustment and timing accuracy
- **Memory System** - Recording and playback features
- **Button/Menu** - UI navigation and gestures
- **Special Features** - Radio mode, touch inputs, TRS detection
- **Settings Persistence** - EEPROM storage across power cycles
- **Stress Tests** - Edge cases and extended use

### Testing Tips

**You don't need to test everything:**
- Skip tests that don't apply to your hardware (e.g., radio features on non-Advanced PCB)
- Focus on critical functionality first (keyer modes, USB output, basic operations)
- Mark N/A items clearly in comments

**Be thorough where it matters:**
- Test the keyer modes you actually use
- Verify settings persist across power cycles (critical!)
- Test memory system if you use it
- Check stress cases (rapid input, long holds, mode switching)

### Reporting Issues

**In the hardware-specific issue:**
1. Check the appropriate box: "No issues" / "Minor issues" / "Critical issues"
2. Use the provided issue report format in the "Issues Found" section
3. Include: Severity, steps to reproduce, expected vs actual behavior
4. For critical bugs, create a separate GitHub issue and link it

**In the parent issue:**
If you found a **critical** bug that blocks release:
1. Comment on the parent overview issue
2. Describe the critical issue briefly
3. Link to the hardware-specific issue with details
4. Tag the maintainer

**Severity Levels:**
- **Critical** - Firmware doesn't work, data loss, device bricking, major feature broken
- **Major** - Important feature not working, but workarounds exist
- **Minor** - Cosmetic issues, edge cases, nice-to-have features

## Example Workflow

### Complete Testing Cycle Example

**Day 1: Development & CI**
- Maintainer merges feature branches to master
- CI automatically builds all firmware variants
- UF2 files attached to the GitHub Release as version-stamped assets

**Day 1: Testing Issues Created**
- Maintainer creates parent overview issue #42 for v2.1.0
- Maintainer creates 8 hardware-specific issues (#43-#50)
- Hardware issues linked to parent issue
- Testers assigned based on available hardware

**Days 2-7: Testing Phase**
- Tester Alice claims issue #44 (XIAO Basic V2), checks off tests as she goes
- Tester Bob claims issue #50 (QT Py Advanced), finds minor buzzer issue ⚠️
- Tester Carol claims issue #43 (XIAO Non-PCB), reports all passing ✅
- Bug issue #51 created for Bob's buzzer issue, fix merged, new firmware built
- Bob retests with new firmware - now passing ✅
- Alice and Carol mark their issues complete with sign-off

**Day 8: Release Decision**
- Maintainer reviews parent issue #42
- Minimum requirements met (3 configs, 3 testers, no critical bugs)
- Updates parent issue: "3/8 configs tested, all passing"
- Maintainer marks parent issue "Ready for Release"
- GitHub release v2.1.0 created with all 8 firmware files
- All testing issues (#42-#50) closed with reference to release

**Day 8: Post-Release**
- Release announced to users
- Testing issues remain as historical documentation
- Users can reference to see which configs were tested

## Benefits of This System

✅ **Hardware-specific testing** - Each config gets thorough, dedicated testing
✅ **Clear ownership** - One tester per hardware config, no confusion
✅ **Collaborative** - Multiple people can test different configs simultaneously
✅ **Scalable** - Easy to see status of all 8 configs at a glance in parent issue
✅ **Comprehensive** - Detailed checklists ensure nothing is missed
✅ **Transparent** - All results visible and linkable
✅ **Documented** - Historical record of exactly what was tested on which hardware
✅ **Flexible** - Can release with 2 configs tested, or wait for more coverage
✅ **Low friction** - No external tools, just GitHub issues
✅ **Trackable** - GitHub shows progress bars based on checked boxes

## Tips & Best Practices

### For Release Managers
- **Create all issues at once** - Parent + 8 hardware issues, link them all together
- **Assign wisely** - Match testers to hardware they actually own
- **Set realistic timeline** - Give testers at least 3-5 days
- **Prioritize diversity** - Better to have 4 different configs than 4 tests of same config
- **Be responsive** - Answer tester questions quickly to unblock them
- **Don't rush** - If critical issues found, fix and retest before release
- **Update parent issue** - Keep the progress summary current so people can see status

### For Testers
- **Claim early** - Add your name as soon as you commit to testing
- **Test systematically** - Work through sections in order, check boxes as you go
- **Focus on critical paths** - Keyer modes, USB output, persistence are most important
- **Power cycle frequently** - Many bugs only show up after restart
- **Document thoroughly** - Good bug reports help maintainers fix issues fast
- **Communicate delays** - If you can't finish, let maintainer know so they can reassign
- **Ask questions** - Better to clarify than test wrong thing

### General
- **Keep templates updated** - Add new test items as firmware features evolve
- **Learn from history** - Review old testing issues to see what bugs were found
- **Use labels effectively** - `testing`, `release`, `critical`, `hardware-specific`
- **Link everything** - Cross-reference related issues, bugs, and releases
- **Celebrate** - Recognize testers' contributions! 🎉

## Troubleshooting

**Q: Do we really need 8 separate testing issues?**
A: Yes! It keeps each hardware config's testing isolated and clear. The parent issue ties them together for easy tracking.

**Q: Can multiple people test the same hardware config?**
A: Yes! The "Additional Testers" section allows multiple people to sign off on the same config. This is great for critical releases.

**Q: What if we can't test all 8 configurations?**
A: That's expected! Minimum is 2 configs. Prioritize:
- Mix of XIAO and QT Py (at least one each)
- Mix of PCB versions (Non-PCB, Basic, Advanced)
- Most common configs your users have

**Q: What if someone finds a critical bug?**
A:
1. Mark it in the hardware-specific issue
2. Create a separate GitHub issue for the bug
3. Add to parent issue's "Critical Issues" section
4. Fix the bug, rebuild all 8 configs
5. Ask testers to retest with new firmware

**Q: How do we handle urgent hotfix releases?**
A: For critical bugs (bricking, security):
- Expedite with just 1-2 configs tested
- Focus on the specific bug area
- Document limited testing in release notes
- Plan full testing for next release

**Q: What if a tester disappears mid-testing?**
A:
- Wait 2-3 days
- Reassign to someone else
- They can pick up where the previous tester left off (checklist shows progress)

**Q: GitHub only allows one person to edit at a time. Is that a problem?**
A: Not really! Most edits are quick (checking a box). If someone's editing, wait 30 seconds and try again.

## Related Documents

- [TESTING_GUIDE.md](TESTING_GUIDE.md) - Detailed manual testing procedures for the firmware update website
- [.github/ISSUE_TEMPLATE/release-testing-overview.md](../.github/ISSUE_TEMPLATE/release-testing-overview.md) - Parent issue template
- [.github/ISSUE_TEMPLATE/release-testing-hardware.md](../.github/ISSUE_TEMPLATE/release-testing-hardware.md) - Hardware-specific issue template
- [.github/workflows/create-release-testing-issues.yml](../.github/workflows/create-release-testing-issues.yml) - The workflow file

## Quick Reference

### Issue Creation Checklist

- [ ] Create parent overview issue with version number
- [ ] Create 8 hardware-specific issues (XIAO × 4 + QT Py × 4)
- [ ] Link hardware issues to parent (add issue numbers)
- [ ] Assign testers to hardware configs they own
- [ ] Attach or link to firmware files
- [ ] Fill in "What's New" section
- [ ] Set target release date

### Release Checklist

- [ ] Minimum 2 hardware configs tested
- [ ] Minimum 2 different testers signed off
- [ ] No critical bugs blocking release
- [ ] CI builds successful for all 8 configs
- [ ] `online-updater/index.html` updated
- [ ] Update parent issue progress summary
- [ ] Mark parent issue "Ready for Release"
- [ ] Create GitHub release
- [ ] Close all testing issues
- [ ] Announce release

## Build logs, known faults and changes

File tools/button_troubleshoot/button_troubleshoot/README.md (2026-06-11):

# Button Hat Troubleshooting Tool

This folder contains a diagnostic tool for testing Vail Adapter button hat PCBs.

## Purpose

The button hat uses a resistor ladder network to read three buttons through a single analog pin. This tool helps diagnose issues by measuring the actual analog values produced by each button combination.

## Files

- `button_troubleshoot.ino` - Arduino sketch source code
- `button_test_qtpy.uf2` - Pre-compiled firmware for QT Py SAMD21 (drag-and-drop ready)
- `button_test_xiao.uf2` - Pre-compiled firmware for Seeeduino XIAO SAMD21 (drag-and-drop ready)
- `build_output/` - Compiled binary files for QT Py (generated by arduino-cli)
- `build_output_xiao/` - Compiled binary files for XIAO (generated by arduino-cli)

## How to Use

### 1. Flash the Firmware

**Option A: Drag-and-Drop (Easy)**

For **QT Py SAMD21**:
1. Connect your QT Py to USB while holding the BOOT button
2. A drive named `QTPY_BOOT` will appear
3. Drag `button_test_qtpy.uf2` onto the drive
4. The board will automatically reboot with the test firmware

For **Seeeduino XIAO SAMD21**:
1. Connect your XIAO to USB
2. Double-click the reset button to enter bootloader mode
3. A drive named `Arduino` will appear
4. Drag `button_test_xiao.uf2` onto the drive
5. The board will automatically reboot with the test firmware

**Option B: Build from Source**

For QT Py:
```bash
cd button_troubleshoot
arduino-cli compile --fqbn adafruit:samd:adafruit_qtpy_m0 --output-dir build_output --export-binaries .
python ../uf2conv.py -c -f 0x68ED2B88 -b 0x2000 build_output/button_troubleshoot.ino.bin -o button_test_qtpy.uf2
```

For XIAO:
```bash
cd button_troubleshoot
arduino-cli compile --fqbn Seeeduino:samd:seeed_XIAO_m0 --output-dir build_output_xiao --export-binaries .
python ../uf2conv.py -c -f 0x68ED2B88 -b 0x2000 build_output_xiao/button_troubleshoot.ino.bin -o button_test_xiao.uf2
```

### 2. Run the Test

1. Open your serial monitor (115200 baud)
   - Arduino IDE: Tools > Serial Monitor
   - PlatformIO: Monitor task
   - Command line: `screen /dev/ttyACM0 115200` (Linux/Mac) or PuTTY (Windows)

2. The tool will display instructions and expected value ranges

3. Follow the prompts:
   - Test 1: Release all buttons, press Enter
   - Test 2: Hold Button 3, press Enter
   - Test 3: Hold Button 2, press Enter
   - Test 4: Hold Button 1, press Enter
   - Test 5: Hold Buttons 2+3 together, press Enter
   - Test 6: Hold Buttons 1+3 together, press Enter
   - Test 7: Hold Buttons 1+2 together, press Enter

4. Review the results summary

### 3. Interpret Results

The tool measures each button combination 50 times and reports:
- **Min/Max**: Range of values (larger range = noisy connections)
- **Avg**: Average value (should be within expected range)
- **Status**: `GOOD` if within expected range, `CHECK` if outside

#### Expected Values for Advanced PCB

| Button State | Expected Range | Typical Value |
|---|---|---|
| None | 0-100 | 0 |
| B3 | 260-300 | 280 |
| B2 | 315-355 | 335 |
| B2+B3 | 377-405 | 397 |
| B1 | 406-435 | 414 |
| B1+B3 | 470-502 | 490 |
| B1+B2 | 503-650 | 516 |

**Note:** V2 Basic PCB has different expected values. See `buttons.cpp` lines 156-189 for V2 ranges.

### 4. Common Issues

**Values Outside Expected Range:**
- Wrong resistor values in the ladder network
- Poor solder joints on resistors or buttons
- Damaged components
- Incorrect PCB version (check if you have Advanced vs V2 Basic)

**Large Range (Max - Min > 20):**
- Noisy connections
- Intermittent contact in buttons
- Loose wires or connectors

**Overlapping Values Between Buttons:**
- Will cause unreliable button detection in normal operation
- Check resistor values and solder joints
- Verify correct resistor placement per schematic

**All Values Near Zero:**
- Button pin not connected to resistor ladder
- Short circuit to ground
- Wrong pin configuration

**All Values Near 1023:**
- Open circuit (no connection to button network)
- Missing pull-down resistor
- Broken trace on PCB

## Restoring Normal Firmware

After testing, flash the normal Vail Adapter firmware:

**For QT Py:**
```bash
# Download the appropriate UF2 from the GitHub Release (or build it locally)
# For QT Py Advanced PCB:
cp qtpy_advanced_pcb.uf2 /media/QTPY_BOOT/
```

**For XIAO:**
```bash
# Download the appropriate UF2 from the GitHub Release (or build it locally)
# For XIAO Advanced PCB:
cp xiao_advanced_pcb.uf2 /media/Arduino/
```

Or use the web updater at https://vailadapter.com

## Technical Details

- **Sampling**: 50 readings per button, 10ms between samples
- **Pin**: Digital pin 3 (A3 analog input on both QT Py and XIAO SAMD21)
- **Resolution**: 10-bit ADC (0-1023 range)
- **Averaging**: Reduces noise from electrical interference
- **Compatibility**: Works with all Vail Adapter PCB versions (same button pin configuration)

## Support

If you get unexpected results:
1. Save the test output
2. Take photos of your button hat PCB (both sides)
3. Report issue with results and photos to Vail Adapter support

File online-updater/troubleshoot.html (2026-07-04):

# Troubleshooting Recorder

Is your Vail device misbehaving? This tool quietly records what it's doing behind the scenes so the messages can be sent in for help. Pick your device, connect it, recreate the problem, then save the file and send it over. Works for both the Vail Adapter and the Vail Summit. Requires Chrome, Edge, or Opera.

This browser can't connect to devices. Please use Chrome, Edge, or Opera on a desktop computer.

ℹ️ Heads up: this tool can only record messages from a device that powers on and starts up. If your device has working firmware on it and boots — even if something isn't behaving right — you're in the right place. If it won't turn on at all, won't accept new firmware, or never finishes starting, there may be nothing here to record; reach out at ke9bos@pigletradio.org or in the Vail Adapter / Vail Summit Discord channel instead.

## 1. Which device needs help?

We'll set everything up for you based on your choice.

📡

### Vail Adapter

The USB adapter that connects your paddles to your computer.

⛰️

### Vail Summit

The standalone trainer with its own screen and keyboard.

## 2. Record what's happening

Device: — (speed set to — automatically)

1

### Plug in & connect

Connect your device with a USB cable, click Connect, then choose it from the list your browser shows.

🔌 Connect ⏏️ Capture Startup (Unplug & Replug) Disconnect 🔄 Restart Device Ready to connect.

2

### Recreate the problem

Leave this page open and do whatever makes the issue happen. Everything the device reports appears in the box below.

Auto-scroll Show times Clear Copy

3

### Save & send it in

Save the recording to a file, then send it over so we can take a look.

💾 Save Recording to a File

Where to send it:

- Email: ke9bos@pigletradio.org
- Discord: drop the file in the Vail Adapter or Vail Summit channel (whichever matches your device)
- GitHub: attach it to an issue on the device's repository

### ❓ Common questions

Nothing shows up in the box

- Make sure you picked the right device at the top.
- Click Restart Device, or press the small RESET button on the device.
- Close any other program that might be using it (Arduino IDE, PuTTY, another monitor).
- Some cables only charge — use one you know transfers data.

"Port in use" or it won't connect (Windows)

Close other programs that talk to the device. If it keeps happening, open Device Manager → Ports (COM & LPT), right-click the device → Disable, wait two seconds, then Enable, and try again.

The Connect button does nothing

This only works in Chrome, Edge, or Opera on a desktop computer. Firefox and Safari can't connect to devices.

Linux: Permission denied

Add your user to the dialout group: sudo usermod -a -G dialout $USER then log out and back in.

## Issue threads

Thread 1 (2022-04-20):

ESP32 Bluetooth as a future suggestion

mgiugliano, 2022-04-20:
ESP32 and its Bluetooth capabilities might be an interesting "wire-less" route to consider (although powering the device would still be cumbersome).

Thank you for your continued efforts and updates :-)

WrathPak, 2025-04-18:
Hi! We are exploring wifi as a method to wirelessly connect with the vail server. I haven't looked into bluetooth much yet but I think someone in the discord has - I'll check and see where they got with it.

WrathPak, 2025-09-20:
Just an update here, this is still being explored. We have a basic prototype hardware dev platform that can support this now.

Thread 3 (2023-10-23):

Does this work with the Seeed Xiao RP2040?

15medium, 2023-10-23:
Does this work with the Seeed Xiao RP2040?
https://wiki.seeedstudio.com/XIAO-RP2040/
Holding the boot button and plugging it in brings up the device but nothing happens when I copy the vail-adapter.xiao.uf2 file to it.
Thanks,
Paul VA3ZC

nealey, 2023-10-23:
No, it doesn't. Thanks for sending me a compile error log in private email, that saved me a bunch of time.

I've updated the documentation to specifically mention the M0 as the board to get. I hope nobody else has tried to get it on the wrong board!

nealey, 2023-10-23:
Fixed in https://github.com/nealey/vail-adapter/commit/36cc1384431d4a01a2066e536f0696d9a95e30b6

Closed 2023-10-23.

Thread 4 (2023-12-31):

Key down LED

g7kse, 2023-12-31:
Hi Neale,

Just ordering some parts for this and will be putting this in a small enclosure from [Hammond](https://www.hammfg.com/files/parts/pdf/1455C801RD.pdf) that I tend to use a bit so I'll adapt the PCB that's in the repo to slide in. Just wondering if adding a key down (TX'ing) LED is possible. The enclosure is 'desktop' so less like the smaller ones and there's obviously loads of space on the board

I would have thought using the buzzer might be a solution without changing code but then I noticed that Pin 10 might be used instead of Pin 9.

Before i go and fab up some PCB's can you let me know if the pin allocations will change and if its practical to take an LED off the buzzer pin?

nealey, 2024-01-01:
Yes, there's a bug with the current PCB, thanks for reminding me. I just opened #4 to track this problem. If you'd like to submit a patch to the PCB files, that would be super great! I'm not very adept at the software that generated them: I don't even remember what it's called.

You should be able to hook an LED up instead of a speaker: I think it uses the same PWM code, so the LED will not be full brightness. I don't have anything nearby to test this out, but if you have a microcontroller, go ahead and hook a sacrificial LED up to it and report back on how it went! The LED should be fine, but you never know, so don't use your favorite LED ;)

A very small code change would make a TX LED easy on another pin. You could `pinMode(8, OUTPUT)` and then, in beginTx and endTx, add `digitalWrite(8, true)` and `digitalWrite(8, false)` respectively, to get that LED going. I'd be glad to accept a patch adding this in, as well: but please use a `#define` instead of a hard-coded pin number :)

nealey, 2024-03-14:
@g7kse I finally got around to investigating: it appears the PCB files checked in have the speaker wired up to the correct pin. The board has 2023-01-22 silkscreened onto it: the ones I ordered are 2023-01-21. I must have realized shortly after I submitted the order that the pin was wrong, fixed it in git, and not bothered ordering a new batch, because I broke out every pin on top of the board anyway.

Anyway, I am strongly opposed to changing pins in the code, so feel encouraged to rely on the current allocations!

I'm going to close this issue, but I'd love to hear if you had any success wiring an LED to the buzzer pin.

nealey, 2024-03-14:
update: the pins are wrong on the part in kicad! I'll fix this.

Closed 2024-03-14.

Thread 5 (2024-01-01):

PCB has wrong pin wired to speaker

nealey, 2024-01-01:
Oops, I hooked pin 9 to the speaker: it should be pin 10.

Someone needs to change the PCB files to use the pin 10 instead!

nealey, 2024-03-14:
It looks like I actually made that change one day after I ordered my current batch of PCBs. The new design also moves the 3.5mm jack over and adds space for a piezo.

nealey, 2024-03-14:
The XIAO pins are incorrectly labelled, actually!

Closed 2024-03-14.

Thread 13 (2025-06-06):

User Changeable Key Bindings When in Keyboard Mode

Nehem11e, 2025-06-06:
A tool that was critical in my Morse code practice was Morse Mania. Unfortunately it uses a non standard key to listen trigger dits and dahs.  Left and Right square brackets “[“  and  “]”

It would be cool if you could use the vail repeater website, where other settings are changed, to set a key binding for the dits and dahs.  Have that setting save to the adapter and then have the adapter send out the new key building

WrathPak, 2025-06-08:
ok, vail repeater is updated at https://vail.fly.dev/ - here is the tool to change it. it is ugly and needs some work, but works.

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

this was kinda  ahuge change to keyboard mode so we should test it a lot
will only accept letters, [ ] / \ leftcontrl right contrl and shift keys as key bindings right now. and there is no error feedback on the ui yet.

[xiao_non_pcb.uf2.zip](https://github.com/user-attachments/files/20642242/xiao_non_pcb.uf2.zip)
[xiao_basic_pcb_v2.uf2.zip](https://github.com/user-attachments/files/20642243/xiao_basic_pcb_v2.uf2.zip)
[xiao_basic_pcb_v1.uf2.zip](https://github.com/user-attachments/files/20642244/xiao_basic_pcb_v1.uf2.zip)
[qtpy_non_pcb.uf2.zip](https://github.com/user-attachments/files/20642245/qtpy_non_pcb.uf2.zip)
[qtpy_basic_pcb_v1.uf2.zip](https://github.com/user-attachments/files/20642240/qtpy_basic_pcb_v1.uf2.zip)
[qtpy_basic_pcb_v2.uf2.zip](https://github.com/user-attachments/files/20642241/qtpy_basic_pcb_v2.uf2.zip)

chickenside, 2025-08-24:
@WrathPak, that link no longer works.  I would also like to try this for Morse Mania.

Closed 2025-09-10.

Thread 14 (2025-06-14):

playVAIL startup function has extra ending dit

EvanBoyar, 2025-06-14:
The function is correctly written to play VAIL in CW.

However, it sounds like it plays an extra dit at the end.

I think what's going on is that adapter.cpp (see case 2 of your switch statement) when it loads from EEPROM, it plays a short confirmation tone that's around as long as a dit. I think you need to add a short delay of a couple hundred ms to have audible separation between the startup and the load completion sounds. Or maybe rm the conf tone if you only want it to say VAIL.

WrathPak, 2025-06-15:
Hi! Thanks for tracking this down - that was definitely it. HAd some confirmation tones there back in the day that I don't think we need now so I removed them. I'll make a new release shortly to address this!

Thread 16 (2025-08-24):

QT Py Advanced PCB UF2: Both paddles register as ControlLeft in keyboard mode

chickenside, 2025-08-24:
Vail Adapter hardware: Adafruit QT Py SAMD21 (M0), Advanced PCB build.  Firmware flashed: qtpy_advanced_pcb.uf2 from the latest release.

Observed behavior (keyboard mode):

In apps that accept keyboard paddles (e.g., VBand, Morse Invaders), paddles work for sending.

In generic key testers (e.g., [keycode.info]) and on [morsecode.world keyer], both paddles register only as ControlLeft. I never see ControlRight.

On the same system, a physical keyboard produces ControlLeft and ControlRight distinctly, so the OS/browser can differentiate the two keys.

Expected behavior:
In keyboard mode, one paddle should emit ControlLeft and the other ControlRight (VBand-style mapping) so sites like morsecode.world can bind both sides independently.

Question / Request:
Am I missing a configuration step for keyboard mode, or does the current QT Py SAMD21 (Advanced PCB) UF2 map both paddles to Left Ctrl? If it’s the latter, could the keyboard report be updated so the right paddle emits Right Ctrl?

Environment:

Board: Adafruit QT Py SAMD21 (M0), Advanced PCB

Firmware: qtpy_advanced_pcb.uf2 (latest release)

OS/Browser: Windows 10, Chrome and Firefox (same result)

Test pages: keycode.info, morsecode.world keyer

Thanks for confirming whether this is usage or a small firmware mapping fix.

WrathPak, 2025-09-20:
I have some time to look at this this weekend, I'll see what I can do.

WrathPak, 2025-10-04:
This has been solved now, and is fixed on the newest release available at https://www.update.vailadapter.com

Closed 2025-10-04.

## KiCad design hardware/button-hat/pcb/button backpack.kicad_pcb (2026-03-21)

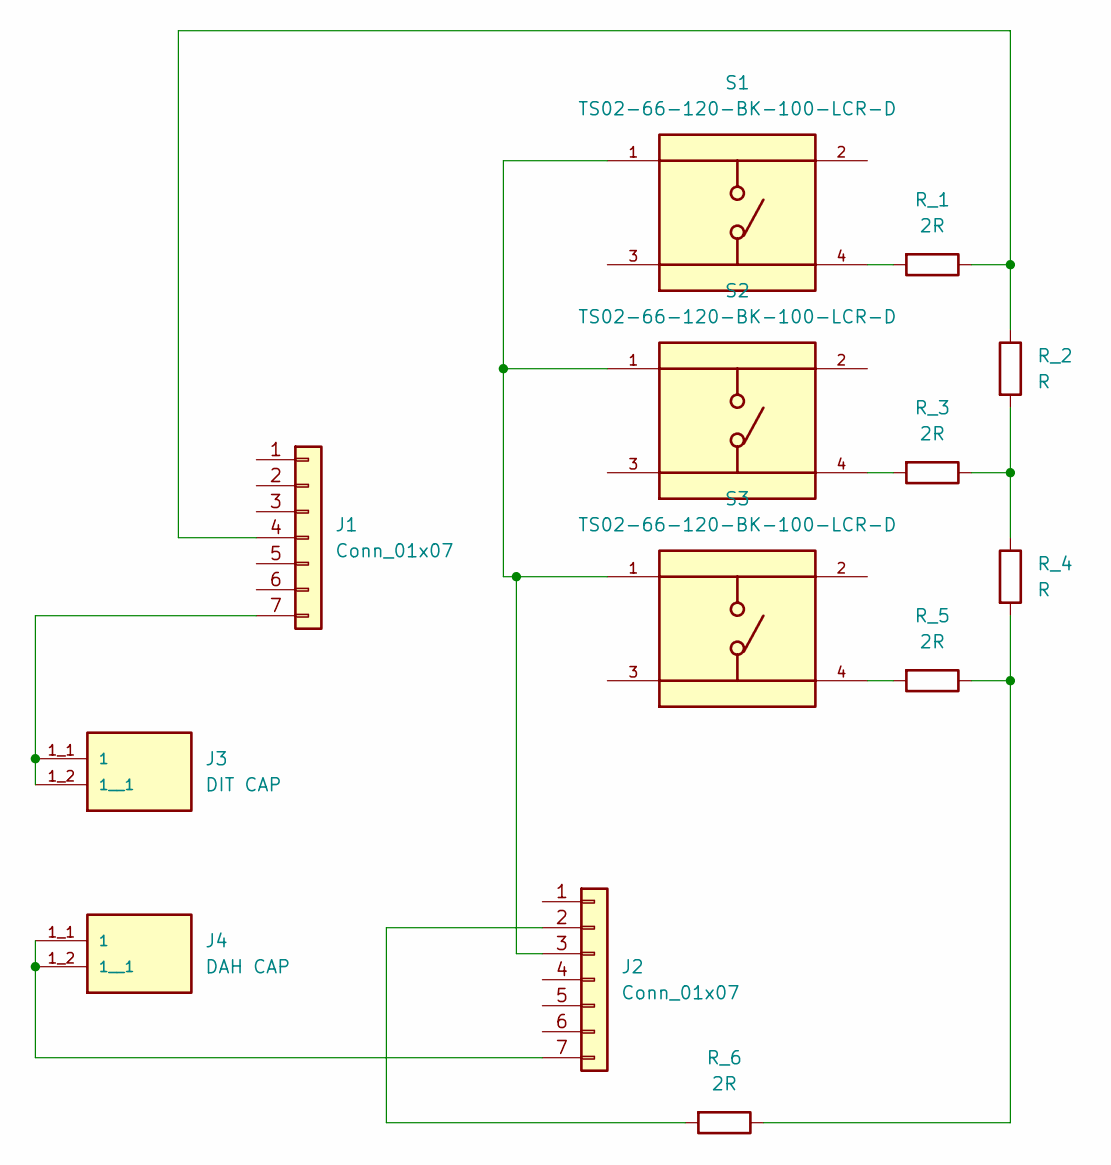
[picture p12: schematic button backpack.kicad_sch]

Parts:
J1, J2: Conn_01x07; PinHeader_1x07_P2.54mm_Vertical
J3: DIT CAP; KEYSTONE_7837; PARTREV 3.14.19
J4: DAH CAP; KEYSTONE_7837; PARTREV 3.14.19
R_1, R_3, R_5, R_6: 2R; R_Axial_DIN0207_L6.3mm_D2.5mm_P10.16mm_Horizontal
R_2, R_4: R; R_Axial_DIN0207_L6.3mm_D2.5mm_P10.16mm_Horizontal
S1, S2, S3: TS02-66-120-BK-100-LCR-D; SW_TS02-66-120-BK-100-LCR-D; PARTREV 1.0

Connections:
unnamed: J1.4, R_1.1, R_2.1
unnamed: J1.7, J3.1_1 (1), J3.1_2 (1__1)
unnamed: J2.2, R_6.2
unnamed: J2.3, S1.1, S2.1, S3.1
unnamed: J2.7, J4.1_1 (1), J4.1_2 (1__1)
unnamed: R_1.2, S1.4
unnamed: R_2.2, R_3.1, R_4.1
unnamed: R_3.2, S2.4
unnamed: R_4.2, R_5.1, R_6.1
unnamed: R_5.2, S3.4

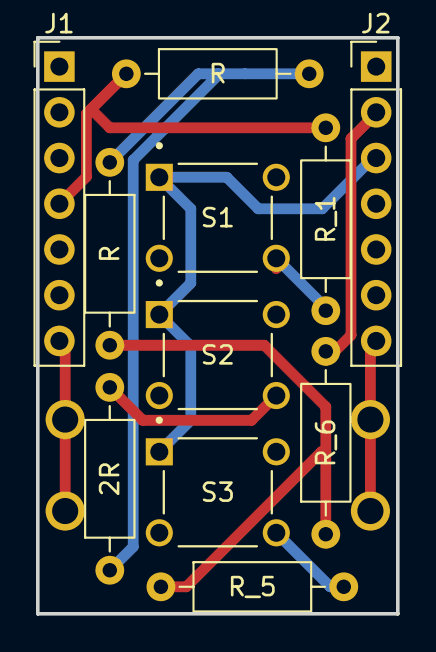
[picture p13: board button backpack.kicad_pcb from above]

Board: 2 copper layers, 20.0 x 32.0 mm, 13 parts (0 on the bottom side), 10 nets.

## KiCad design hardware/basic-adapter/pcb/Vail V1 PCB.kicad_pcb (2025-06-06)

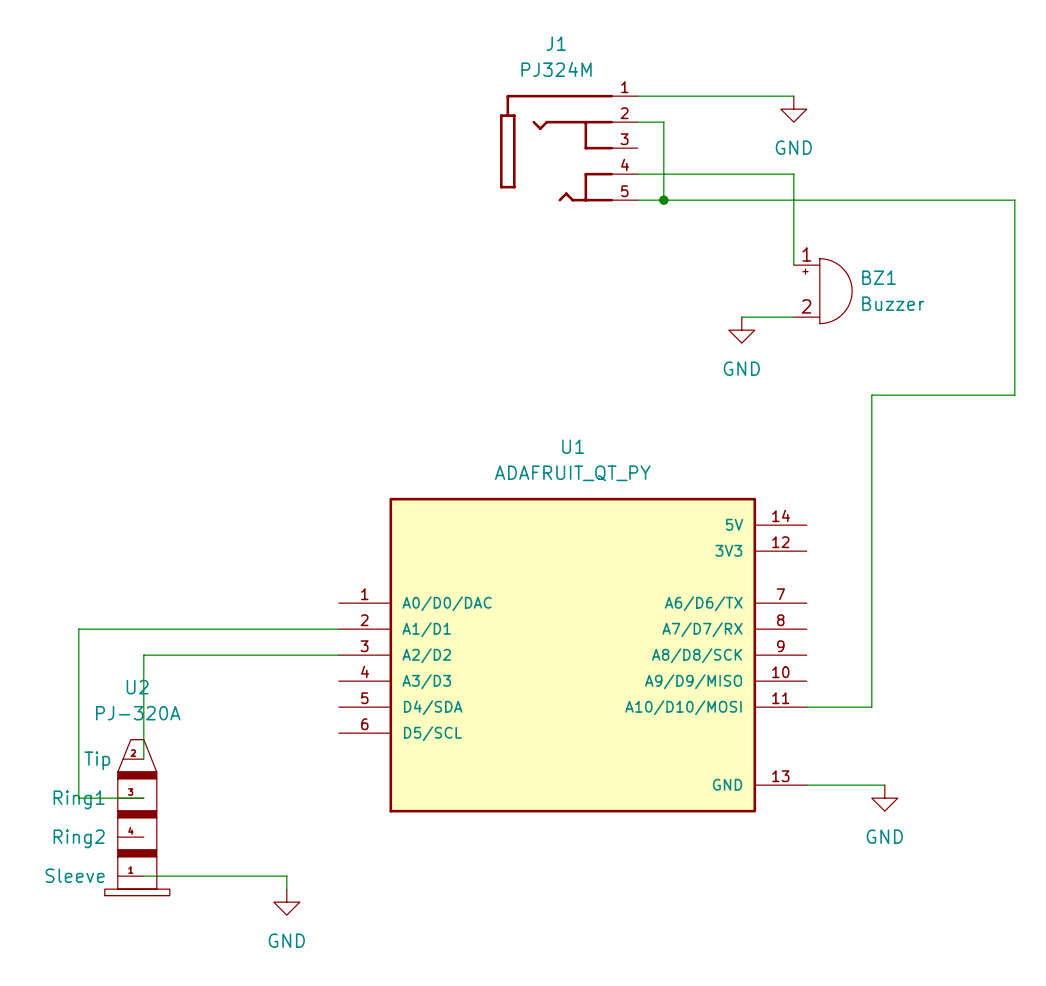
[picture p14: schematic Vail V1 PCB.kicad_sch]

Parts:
BZ1: Buzzer; Buzzer_15x7.5RM7.6
J1: PJ324M; WENZHOU_PJ324M; PARTREV N/A
U1: ADAFRUIT_QT_PY; MODULE_ADAFRUIT_QT_PY; PARTREV 2022-12-12
U2: PJ-320A; TRRS-PJ-320A

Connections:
GND: BZ1.2 (-), J1.1, U1.13 (GND), U2.1 (Sleeve)
unnamed: BZ1.1 (+), J1.4
unnamed: U1.2 (A1/D1), U2.3 (Ring1)
unnamed: U1.3 (A2/D2), U2.2 (Tip)
unnamed: J1.2, J1.5, U1.11 (A10/D10/MOSI)

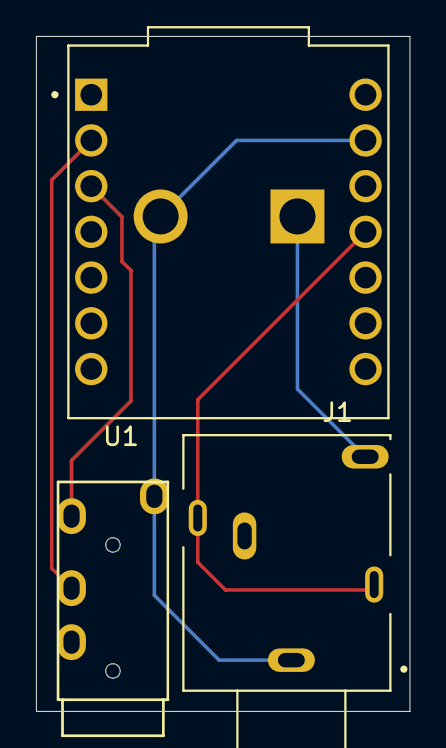
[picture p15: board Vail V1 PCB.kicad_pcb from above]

Board: 2 copper layers, 20.8 x 37.5 mm, 4 parts (1 on the bottom side), 5 nets.

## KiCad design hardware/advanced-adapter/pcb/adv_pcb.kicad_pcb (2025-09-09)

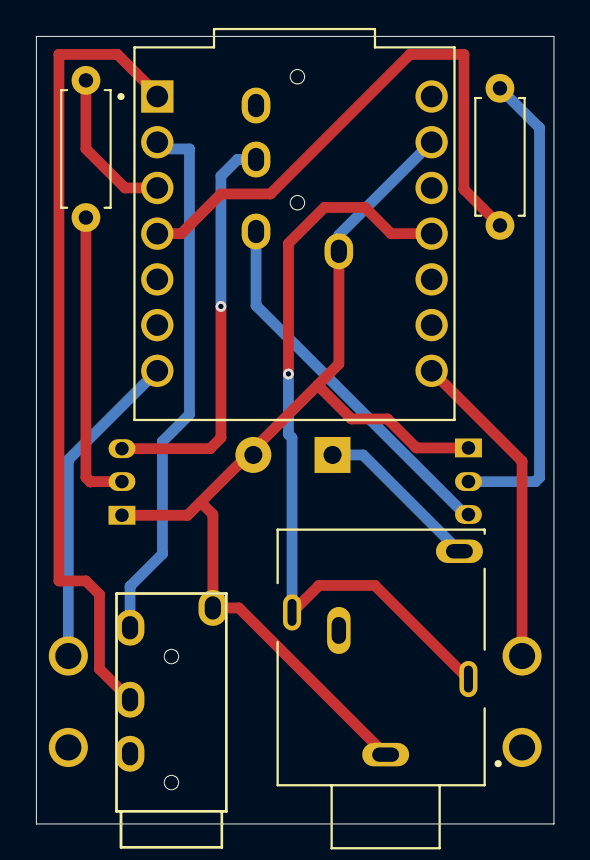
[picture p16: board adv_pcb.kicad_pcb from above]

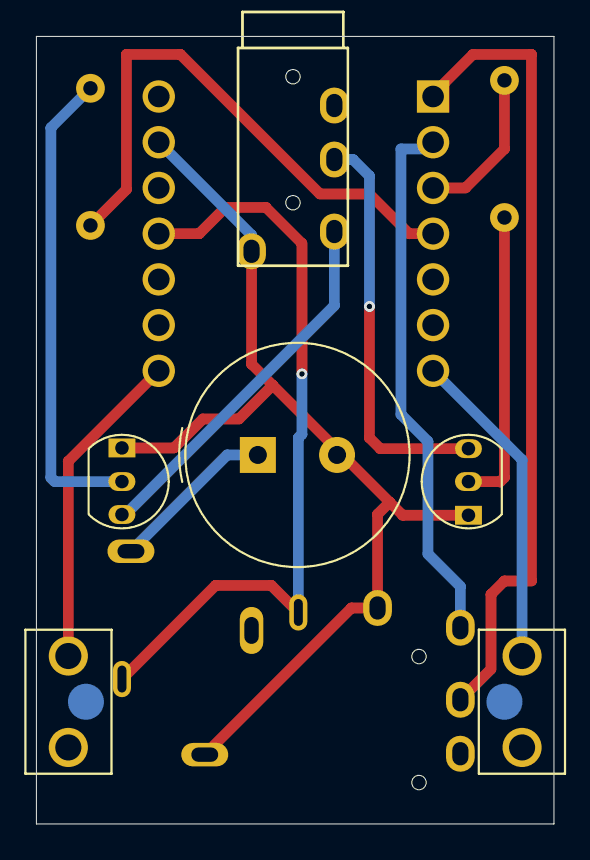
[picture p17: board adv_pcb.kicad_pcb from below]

Board: 2 copper layers, 28.8 x 43.8 mm, 13 parts (8 on the bottom side), 13 nets.

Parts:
BZ1: Buzzer; Buzzer_TDK_PS1240P02BT_D12.2mm_H6.5mm
DAH2: PN2222A; TO-92_Inline
DIT2: PN2222A; TO-92_Inline
Dah1: 7837; KEYSTONE_7837
Dit1: 7837; KEYSTONE_7837
J1: headphone; WENZHOU_PJ324M
R1, R2: R; R_Axial_DIN0207_L6.3mm_D2.5mm_P7.62mm_Horizontal
TP1, TP2: TestPoint; TestPoint_Pad_D4.0mm
U1: ADAFRUIT_QT_PY; MODULE_ADAFRUIT_QT_PY
U2: Output to Radio; TRRS-PJ-320A
U3: Key Input; TRRS-PJ-320A

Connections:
GND: BZ1.2 (-), DAH2.1 (E), DIT2.1 (E), J1.1, U1.13 (GND), U2.1 (Sleeve), U3.1 (Sleeve)
unnamed: BZ1.1 (+), J1.4
unnamed: DAH2.2 (B), R1.1
unnamed: DAH2.3 (C), U2.3 (Ring1)
unnamed: DIT2.2 (B), R2.1
unnamed: DIT2.3 (C), U2.2 (Tip)
unnamed: Dah1.1_2 (1__1), U1.8 (A7/D7/RX)
unnamed: Dit1.1_1 (1), U1.7 (A6/D6/TX)
unnamed: U1.1 (A0/D0/DAC), U3.3 (Ring1)
unnamed: U1.2 (A1/D1), U3.2 (Tip)
unnamed: R1.2, U1.3 (A2/D2)
unnamed: R2.2, U1.4 (A3/D3)
unnamed: J1.2, J1.5, U1.11 (A10/D10/MOSI)

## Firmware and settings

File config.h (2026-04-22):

#ifndef CONFIG_H
#define CONFIG_H

// --- SELECT YOUR HARDWARE CONFIGURATION ---
// Uncomment only one of the following lines based on your build:
// #define V1_Basic_PCB
// #define V2_Basic_PCB
// #define Advanced_PCB
#define NO_PCB_GITHUB_SPECS
// #define TRRS_TRINKEY
// #define ARDUINO_MICRO_BOARD

// --- PIN DEFINITIONS BASED ON SELECTION ---

#ifdef V1_Basic_PCB
  #define DIT_PIN 1
  #define DAH_PIN 0
  #define KEY_PIN 9
  #define QT_DIT_PIN A6
  #define QT_DAH_PIN A7
  #define QT_KEY_PIN A8
  #define PIEZO_PIN 10
  #define BUTTON_PIN 3  // R2R button ladder input (pin 3 on QT Py)
  #define LED_ON true
  #define LED_OFF (!LED_ON)
  #define BOARD_NAME "V1 Basic PCB"
  // Radio pins not defined, so HAS_RADIO_OUTPUT will not be defined
#endif

#ifdef V2_Basic_PCB
  #define DIT_PIN 2
  #define DAH_PIN 1
  #define KEY_PIN 0
  #define QT_DIT_PIN A6
  #define QT_DAH_PIN A7
  // #define QT_KEY_PIN A8  // Not used on V2 Basic PCB with button hat
  #define PIEZO_PIN 10
  #define BUTTON_PIN 8  // R2R button ladder input (A8, requires button hat wire mod from A4)
  #define LED_ON true
  #define LED_OFF (!LED_ON)
  #define BOARD_NAME "V2 Basic PCB"
  // Radio pins not defined, so HAS_RADIO_OUTPUT will not be defined
#endif

#ifdef Advanced_PCB
  #define DIT_PIN 1
  #define DAH_PIN 0
  #define KEY_PIN 9
  #define QT_DIT_PIN A7
  #define QT_DAH_PIN A6
  // #define QT_KEY_PIN A8  // Not used on Advanced PCB
  #define PIEZO_PIN 10
  #define BUTTON_PIN 8  // R2R button ladder input (A8 to avoid conflict with radio pins A2/A3)
  #define LED_ON true
  #define LED_OFF (!LED_ON)
  #define BOARD_NAME "Advanced PCB"
  // Radio Output Pins for Advanced PCB
  #define RADIO_DIT_PIN A3
  #define RADIO_DAH_PIN A2
  #define HAS_RADIO_OUTPUT // Signal that radio output pins are configured
#endif

#ifdef NO_PCB_GITHUB_SPECS
  #define DIT_PIN 2
  #define DAH_PIN 1
  #define KEY_PIN 0
  #define QT_DIT_PIN A6
  #define QT_DAH_PIN A7
  #define QT_KEY_PIN A8
  #define PIEZO_PIN 10
  #define BUTTON_PIN 3  // R2R button ladder input (pin 3 on QT Py)
  #define LED_ON false // Xiao inverts this logic
  #define LED_OFF (!LED_ON)
  #define BOARD_NAME "No PCB (GitHub Specs)"
  // Radio pins not defined, so HAS_RADIO_OUTPUT will not be defined
#endif

#ifdef ARDUINO_MICRO_BOARD
  // Arduino Micro (ATmega32U4) — AVR/5V board.
  // This target is memory-constrained and plug-and-play only:
  //   - No capacitive touch hardware (ATmega32U4 lacks FreeTouch)
  //   - No button menu (no resistor ladder supported in current design)
  //   - No built-in LED state changes
  //   - 1024 bytes EEPROM (vs 16KB Flash-emulated on SAMD21)
  #define DIT_PIN 2
  #define DAH_PIN 1
  #define KEY_PIN 0
  #define PIEZO_PIN 10
  // BUTTON_PIN intentionally not defined — no menu on Micro
  #define NO_CAPACITIVE_TOUCH
  #define NO_LED
  #define LED_ON true
  #define LED_OFF (!LED_ON)
  #define BOARD_NAME "Arduino Micro"
  // Optional radio outputs on Micro (A2/A3 are 5V — verify radio tolerance):
  // #define RADIO_DIT_PIN A3
  // #define RADIO_DAH_PIN A2
  // #define HAS_RADIO_OUTPUT

  // EEPROM/RAM-constrained: ATmega32U4 has 1024 bytes EEPROM (vs 16KB on SAMD21)
  // and only 2560 bytes RAM. Shrink CW memory slot dimensions to fit.
  //   3 slots × (100 transitions × 2 bytes + 2 length bytes) = 606 bytes EEPROM
  //   Plus 6 bytes settings = 612 bytes EEPROM used / 1024 available.
  //   Each in-RAM CWMemory is 202 bytes; 3 slots + RecordingState ≈ ~800 bytes RAM.
  #define MAX_MEMORY_SLOTS 3
  #define MAX_TRANSITIONS_PER_MEMORY 100
  #define MAX_RECORDING_DURATION_MS 12000
#endif

#ifdef TRRS_TRINKEY
  // TRRS Jack Pins (using TIP and RING1 for dit/dah)
  #define DIT_PIN 0       // PIN_TIP - connected to tip of TRRS jack
  #define DAH_PIN 2       // PIN_RING1 - connected to ring 1 of TRRS jack
  #define KEY_PIN 0       // Same as DIT_PIN for straight key mode (TRS cable uses tip only)
  // TRRS Jack ground pins - must be driven LOW for proper operation
  #define SLEEVE_PIN 5    // PIN_SLEEVE - ground for TRS/TRRS cable
  #define RING2_PIN 4     // PIN_RING2 - additional ground (optional)
  // Trinkey doesn't have capacitive touch hardware - disable it
  #define NO_CAPACITIVE_TOUCH
  #define PIEZO_PIN 7     // SDA/PA08 on STEMMA QT connector (D7) - wire buzzer here
  // Trinkey uses NeoPixel (requires special library) - disable LED control
  #define NO_LED
  #define LED_BUILTIN 1   // Define but don't use - Trinkey has NeoPixel on pin 1
  #define LED_ON true
  #define LED_OFF (!LED_ON)
  #define BOARD_NAME "TRRS Trinkey"
  // No button ladder on Trinkey - menu functionality not available
  // BUTTON_PIN intentionally not defined
  // Radio pins not defined, so HAS_RADIO_OUTPUT will not be defined
#endif

// --- RADIO KEYING POLARITY ---
// Set to true if your radio PTT/KEY line activates when pulled LOW.
// Set to false if your radio PTT/KEY line activates when pulled HIGH.
#define RADIO_KEYING_ACTIVE_LOW false // <<<< ADJUST THIS FOR YOUR RADIO

#ifdef HAS_RADIO_OUTPUT
  #if RADIO_KEYING_ACTIVE_LOW
    #define RADIO_ACTIVE_LEVEL LOW
    #define RADIO_INACTIVE_LEVEL HIGH
  #else
    #define RADIO_ACTIVE_LEVEL HIGH
    #define RADIO_INACTIVE_LEVEL LOW
  #endif
#endif


// --- COMMON DEFINITIONS ---
#define DIT_KEYBOARD_KEY KEY_LEFT_CTRL
#define DAH_KEYBOARD_KEY KEY_RIGHT_CTRL
#define DEFAULT_TONE_NOTE 69
#define DEFAULT_ADAPTER_DIT_DURATION_MS 100

#define MILLISECOND 1
// NOTE: a `#define SECOND (1000 * MILLISECOND)` used to live here but was
// never referenced in the codebase. Recent Adafruit FreeTouch / ASF headers
// now define SECOND as an enum/constant, which collides with a macro
// redefinition and breaks every SAMD21 compile that includes FreeTouch.
// (Trinkey and Micro skip FreeTouch via NO_CAPACITIVE_TOUCH and were fine.)

// Morse code timing at 20 WPM (for startup sound, not for keyer logic directly)
#define DOT_DURATION 60
#define DASH_DURATION (DOT_DURATION * 3)
#define ELEMENT_SPACE (DOT_DURATION)
#define CHAR_SPACE (DOT_DURATION * 3)
#define WORD_SPACE (DOT_DURATION * 7)

// EEPROM definitions
#define EEPROM_KEYER_TYPE_ADDR 0
#define EEPROM_DIT_DURATION_ADDR 1
#define EEPROM_TX_NOTE_ADDR 3
#define EEPROM_VALID_FLAG_ADDR 4
#define EEPROM_RADIO_KEYER_MODE_ADDR 5
#define EEPROM_VALID_VALUE 0x42

// Feature activation thresholds
#define DIT_HOLD_BUZZER_DISABLE_THRESHOLD 5000   // 5 seconds
#define DAH_SPAM_COUNT_RADIO_MODE 10
#define DAH_SPAM_WINDOW 500
#define DAH_HOLD_RADIO_KEYER_TOGGLE_THRESHOLD 5000  // 5 seconds in radio mode
#define KEY_HOLD_DISABLE_THRESHOLD 6000

#endif // CONFIG_H

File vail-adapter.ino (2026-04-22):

#include "config.h"

#include <MIDIUSB.h>
#include <Keyboard.h>
#ifndef NO_CAPACITIVE_TOUCH
#include <Adafruit_FreeTouch.h>
#endif
#include "bounce2.h"
#include "touchbounce.h"
#include "adapter.h"
#include "buttons.h"
#include "memory.h"
#include "morse_audio.h"
#include "settings_eeprom.h"
#include "menu_handler.h"
#include "equal_temperament.h"

bool trs = false;
unsigned long dahGroundedStartTime = 0;  // Track how long DAH has been grounded
bool dahWasGroundedLastCheck = false;    // Previous state for edge detection
unsigned long lastTrsCheckTime = 0;      // Last time we checked for TRS
const unsigned long TRS_DETECTION_THRESHOLD = 1000;  // 1 second of continuous grounding = TRS cable
const unsigned long TRS_CHECK_INTERVAL = 500;        // Check every 500ms

Bounce dit = Bounce();
Bounce dah = Bounce();
Bounce key = Bounce();
#ifndef NO_CAPACITIVE_TOUCH
TouchBounce qt_dit = TouchBounce();
TouchBounce qt_dah = TouchBounce();
TouchBounce qt_key = TouchBounce();
#endif

VailAdapter adapter = VailAdapter(PIEZO_PIN);

#ifdef BUTTON_PIN
ButtonDebouncer buttonDebouncer;

// CW Memory system
CWMemory memorySlots[MAX_MEMORY_SLOTS];  // 3 memory slots
RecordingState recordingState;           // Current recording state
PlaybackState playbackState;             // Current playback state
#endif

void setup() {
  Serial.begin(9600);
  delay(500);
  Serial.print("\n\nVail Adapter starting on: ");
  Serial.println(BOARD_NAME);

#ifndef NO_LED
  pinMode(LED_BUILTIN, OUTPUT);
  digitalWrite(LED_BUILTIN, LED_OFF);
#endif

#ifdef BUTTON_PIN
  pinMode(BUTTON_PIN, INPUT);
  Serial.println("Button input initialized on pin 3");
#endif

  dit.attach(DIT_PIN, INPUT_PULLUP);
  dah.attach(DAH_PIN, INPUT_PULLUP);
#ifndef TRRS_TRINKEY
  // Trinkey doesn't need separate straight key pin - KEY_PIN same as DIT_PIN
  key.attach(KEY_PIN, INPUT_PULLUP);
#endif

#ifdef TRRS_TRINKEY
  // Configure TRRS jack ground pins - required for switched TRRS jack
  pinMode(SLEEVE_PIN, OUTPUT);
  digitalWrite(SLEEVE_PIN, LOW);
  pinMode(RING2_PIN, OUTPUT);
  digitalWrite(RING2_PIN, LOW);
  Serial.println("TRRS ground pins (SLEEVE, RING2) configured as OUTPUT LOW");

  // Increase debounce interval for TRRS jack pins - they have different electrical characteristics
  dit.interval(25);  // Increased from default 10ms to 25ms
  dah.interval(25);
  key.interval(25);
  Serial.println("Debounce intervals increased to 25ms for TRRS jack stability");
#endif

#ifndef NO_CAPACITIVE_TOUCH
  // Attach capacitive touch with calibrated per-pad thresholds
  qt_dit.attach(QT_DIT_PIN, QT_DIT_THRESHOLD_PRESS, QT_DIT_THRESHOLD_RELEASE);
  qt_dah.attach(QT_DAH_PIN, QT_DAH_THRESHOLD_PRESS, QT_DAH_THRESHOLD_RELEASE);
#ifdef QT_KEY_PIN
  qt_key.attach(QT_KEY_PIN, QT_DIT_THRESHOLD_PRESS, QT_DIT_THRESHOLD_RELEASE); // Use DIT thresholds for KEY
#endif
#endif

#ifdef HAS_RADIO_OUTPUT
  pinMode(RADIO_DIT_PIN, OUTPUT);
  pinMode(RADIO_DAH_PIN, OUTPUT);
  digitalWrite(RADIO_DIT_PIN, RADIO_INACTIVE_LEVEL); // Use configured inactive level
  digitalWrite(RADIO_DAH_PIN, RADIO_INACTIVE_LEVEL); // Use configured inactive level
  Serial.print("Radio Output Pins Initialized. Inactive Level: ");
  Serial.println(RADIO_INACTIVE_LEVEL == LOW ? "LOW" : "HIGH");
#endif

  // Initialize audio module
  initMorseAudio(&adapter, PIEZO_PIN);

  uint8_t startupTone = loadToneFromEEPROM();
  Serial.println("Playing VAIL in Morse code at 20 WPM");
  playVAIL(startupTone);

  loadSettingsFromEEPROM(adapter);
  loadRadioKeyerModeFromEEPROM(adapter);

#ifdef BUTTON_PIN
  loadMemoriesFromEEPROM(memorySlots);
  // Connect recording state to adapter for key capture
  adapter.setRecordingState(&recordingState);
  // Initialize menu handler with flush callback
  initMenuHandler(&adapter, memorySlots, &recordingState, &playbackState, flushBounceState);
#endif

  Serial.print("Adapter settings loaded - Keyer: "); Serial.print(adapter.getCurrentKeyerType());
  Serial.print(", Dit Duration (ms): "); Serial.print(adapter.getDitDuration());
  Serial.print(", TX Note: "); Serial.println(adapter.getTxNote());
  Serial.print("Buzzer initially: "); Serial.println(adapter.isBuzzerEnabled() ? "ON" : "OFF");
  Serial.print("Radio Mode initially: "); Serial.println(adapter.isRadioModeActive() ? "ON" : "OFF");
  Serial.print("Radio Keyer Mode initially: "); Serial.println(adapter.isRadioKeyerMode() ? "ON" : "OFF");

  Keyboard.begin();
  MidiUSB.flush();

  // Ensure clean keyboard state on startup
  adapter.ReleaseAllKeys();

  for (int i = 0; i < 16; i++) {
    delay(20);
    dah.update();
  }
  if (dah.read() == LOW) {
    trs = true;
    Serial.println("TRS plug potentially detected (DAH pin grounded).");
  }
}

void flushBounceState() {
  // Flush the Bounce state by updating multiple times without processing
  // This clears any stale "pressed" states after mode changes
  for (int i = 0; i < 3; i++) {
    dit.update();
    dah.update();
    key.update();
    delay(5);
  }
  Serial.println("Flushed Bounce state for dit/dah/key inputs");
}

void setLED() {
#ifndef NO_LED
  bool finalLedState = false;

  if (adapter.isRadioModeActive()) {
    finalLedState = (millis() % 400 < 200);
  } else if (!adapter.isBuzzerEnabled()) {
    finalLedState = (millis() % 2000 < 1000);
  } else {
    finalLedState = adapter.KeyboardMode();
  }
  digitalWrite(LED_BUILTIN, finalLedState ? LED_ON : LED_OFF);
#endif
}

void loop() {
  unsigned long currentTime = millis();
  midiEventPacket_t event = MidiUSB.read();

  setLED();
  adapter.Tick(currentTime);

  // Check for TRS cable hot-plug detection (every 500ms)
  // ONLY active when already in Straight Key mode (keyer type 1)
  // This requires user to manually switch to Straight Key mode before hot-plugging
  if (currentTime - lastTrsCheckTime >= TRS_CHECK_INTERVAL) {
    lastTrsCheckTime = currentTime;

    // Only check for TRS if we're in Straight Key mode (keyer type 1)
    bool inStraightKeyMode = (adapter.getCurrentKeyerType() == 1);

    if (inStraightKeyMode && !trs) {
      // Check if DAH pin is currently grounded (physical pin only, not capacitive)
      bool dahIsGrounded = (digitalRead(DAH_PIN) == LOW);

      if (dahIsGrounded) {
        if (!dahWasGroundedLastCheck) {
          // DAH just became grounded - start timer
          dahGroundedStartTime = currentTime;
          dahWasGroundedLastCheck = true;
        } else {
          // DAH has been continuously grounded - check duration
          unsigned long groundedDuration = currentTime - dahGroundedStartTime;
          if (groundedDuration >= TRS_DETECTION_THRESHOLD) {
            // TRS cable detected! DAH has been continuously grounded for 1+ second
            trs = true;
            Serial.println("TRS CABLE DETECTED (hot-plug): DAH pin grounded while in Straight Key mode");
            Serial.println("Enabling TRS mode: DIT pin will be used for straight key input, DAH pin ignored");

            // Flush bounce state to clear any pending transitions
            flushBounceState();

            Serial.println("TRS mode active. Straight key input via DIT pin.");
          }
        }
      } else {
        dahWasGroundedLastCheck = false;
        dahGroundedStartTime = 0;
      }
    } else if (trs) {
      // If we're in TRS mode, check if cable was unplugged
      bool dahIsGrounded = (digitalRead(DAH_PIN) == LOW);
      if (!dahIsGrounded) {
        // DAH is no longer grounded - cable unplugged
        Serial.println("TRS cable unplugged (DAH no longer grounded)");
        trs = false;
        dahWasGroundedLastCheck = false;
        dahGroundedStartTime = 0;
      }
    } else {
      // Not in straight key mode and not in TRS mode - reset detection state
      dahWasGroundedLastCheck = false;
      dahGroundedStartTime = 0;
    }
  }

#ifdef BUTTON_PIN
  MenuHandlerState& menuState = getMenuState();

  // Update memory playback state machine
  updatePlayback(playbackState);

  // Control output during playback
  static bool lastPlaybackKeyState = false;
  static bool wasPlaying = false;

  if (playbackState.isPlaying) {
    wasPlaying = true;
    if (playbackState.keyCurrentlyDown != lastPlaybackKeyState) {
      if (playbackState.keyCurrentlyDown) {
        // Key down
        if (menuState.currentMode == MODE_PLAYING_MEMORY) {
          // Normal mode playback: use BeginTx(relay) to pass paddle info for radio mode
          // Convert paddle flag (0=DIT, 1=DAH) to PADDLE enum (PADDLE_DIT=0, PADDLE_DAH=1)
          int relay = (playbackState.currentPaddle == 0) ? PADDLE_DIT : PADDLE_DAH;
          adapter.BeginTx(relay);
        } else {
          // Memory management mode: piezo only (bypass buzzer enable check)
          // Convert MIDI note to frequency
          uint8_t midiNote = adapter.getTxNote();
          int frequency = GET_EQUAL_TEMPERAMENT_NOTE(midiNote);
          tone(PIEZO_PIN, frequency);
        }
      } else {
        // Key up
        if (menuState.currentMode == MODE_PLAYING_MEMORY) {
          // Normal mode playback: use EndTx(relay) to pass paddle info for radio mode
          // Convert paddle flag (0=DIT, 1=DAH) to PADDLE enum (PADDLE_DIT=0, PADDLE_DAH=1)
          int relay = (playbackState.currentPaddle == 0) ? PADDLE_DIT : PADDLE_DAH;
          adapter.EndTx(relay);
        } else {
          // Memory management mode: piezo only
          noTone(PIEZO_PIN);
        }
      }
      lastPlaybackKeyState = playbackState.keyCurrentlyDown;
    }
  } else if (wasPlaying) {
    // Playback just finished
    // The playback state machine ensures key is already released before stopping,
    // so we don't need to call EndTx here (it would be a duplicate)
    if (menuState.currentMode != MODE_PLAYING_MEMORY) {
      // Memory management mode: ensure piezo is off
      noTone(PIEZO_PIN);
    }
    lastPlaybackKeyState = false;
    wasPlaying = false;

    // Return to appropriate mode
    if (menuState.currentMode == MODE_PLAYING_MEMORY) {
      menuState.currentMode = MODE_NORMAL;
      Serial.println("Playback finished - returned to normal mode");
    }
  }

  // Check for recording timeout (25 seconds) or max transitions
  if (recordingState.isRecording) {
    if (recordingState.hasReachedMaxDuration() || recordingState.hasReachedMaxTransitions()) {
      uint8_t activeSlot = recordingState.slotNumber;
      Serial.println("Recording auto-stopped (timeout or max transitions reached)");
      stopRecording(recordingState, memorySlots[activeSlot]);
      saveMemoryToEEPROM(activeSlot, memorySlots[activeSlot]);

      // Play completion tone
      playAdjustmentBeep(false);
      delay(100);
      playAdjustmentBeep(true);
      delay(100);
      playAdjustmentBeep(true);

      menuState.currentMode = MODE_MEMORY_MANAGEMENT;
      Serial.println("Returned to memory management mode");
    }
  }

  // Update menu handler (handles all button logic)
  updateMenuHandler(currentTime, buttonDebouncer);
#endif

  if (event.header) {
    adapter.HandleMIDI(event);
  }

#ifndef TRRS_TRINKEY
  // Trinkey doesn't process separate straight key input
  if (key.update()) {
    adapter.ProcessPaddleInput(PADDLE_STRAIGHT, !key.read(), false);
#ifdef BUTTON_PIN
    // Reset activity timer on CW key activity in setting modes
    if (menuState.currentMode != MODE_NORMAL) {
      menuState.lastActivityTime = currentTime;
    }
#endif
  }
#endif

  if (trs) {
    // TRS mode: DAH pin is grounded (ring shorted to sleeve)
    // DIT pin (tip) is the actual straight key input
    // Only process DIT as straight key, ignore DAH completely
    if (dit.update()) {
      adapter.ProcessPaddleInput(PADDLE_STRAIGHT, !dit.read(), false);
#ifdef BUTTON_PIN
      // Reset activity timer on CW key activity in setting modes
      if (menuState.currentMode != MODE_NORMAL) {
        menuState.lastActivityTime = currentTime;
      }
#endif
    }
    // Update DAH to keep Bounce state current, but don't process it
    dah.update();
  } else {
    // Normal paddle mode: process both DIT and DAH separately
    if (dit.update()) {
      adapter.ProcessPaddleInput(PADDLE_DIT, !dit.read(), false);
#ifdef BUTTON_PIN
      // Reset activity timer on CW key activity in setting modes
      if (menuState.currentMode != MODE_NORMAL) {
        menuState.lastActivityTime = currentTime;
      }
#endif
    }
    if (dah.update()) {
      adapter.ProcessPaddleInput(PADDLE_DAH, !dah.read(), false);
#ifdef BUTTON_PIN
      // Reset activity timer on CW key activity in setting modes
      if (menuState.currentMode != MODE_NORMAL) {
        menuState.lastActivityTime = currentTime;
      }
#endif
    }
  }

#ifndef NO_CAPACITIVE_TOUCH
#ifdef QT_KEY_PIN
  if (qt_key.update()) {
    adapter.ProcessPaddleInput(PADDLE_STRAIGHT, qt_key.read(), true);
#ifdef BUTTON_PIN
    if (menuState.currentMode != MODE_NORMAL) {
      menuState.lastActivityTime = currentTime;
    }
#endif
  }
#endif
  if (qt_dit.update()) {
    adapter.ProcessPaddleInput(PADDLE_DIT, qt_dit.read(), true);
#ifdef BUTTON_PIN
    if (menuState.currentMode != MODE_NORMAL) {
      menuState.lastActivityTime = currentTime;
    }
#endif
  }
  if (qt_dah.update()) {
    adapter.ProcessPaddleInput(PADDLE_DAH, qt_dah.read(), true);
#ifdef BUTTON_PIN
    if (menuState.currentMode != MODE_NORMAL) {
      menuState.lastActivityTime = currentTime;
    }
#endif
  }
#endif
}

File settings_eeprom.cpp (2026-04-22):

#include "settings_eeprom.h"
#include "config.h"
#include <Arduino.h>
#if defined(ARDUINO_ARCH_SAMD)
  // SAMD21 has no true EEPROM — FlashStorage_SAMD emulates it in Flash
  // and requires an explicit EEPROM.commit() to flush writes.
  #include <FlashStorage_SAMD.h>
  #define EEPROM_NEEDS_COMMIT 1
#else
  // AVR (e.g. Arduino Micro ATmega32U4) has native EEPROM; writes are
  // committed per-byte by the hardware, and EEPROM.commit() is not provided.
  #include <EEPROM.h>
#endif
#include <MIDIUSB.h>

static inline void eeprom_commit() {
#ifdef EEPROM_NEEDS_COMMIT
  EEPROM.commit();
#endif
}

// ============================================================================
// Adapter Settings EEPROM Functions
// ============================================================================

uint8_t loadToneFromEEPROM() {
  if (EEPROM.read(EEPROM_VALID_FLAG_ADDR) == EEPROM_VALID_VALUE) {
    uint8_t txNote = EEPROM.read(EEPROM_TX_NOTE_ADDR);
    return txNote;
  } else {
    Serial.println("EEPROM not initialized, using default tone");
    return DEFAULT_TONE_NOTE;
  }
}

void saveSettingsToEEPROM(uint8_t keyerType, uint16_t ditDuration, uint8_t txNote) {
  EEPROM.write(EEPROM_KEYER_TYPE_ADDR, keyerType);
  EEPROM.put(EEPROM_DIT_DURATION_ADDR, ditDuration);
  EEPROM.write(EEPROM_TX_NOTE_ADDR, txNote);
  EEPROM.write(EEPROM_VALID_FLAG_ADDR, EEPROM_VALID_VALUE);
  eeprom_commit();
  Serial.print("Saved to EEPROM - Keyer: "); Serial.print(keyerType);
  Serial.print(", Dit Duration: "); Serial.print(ditDuration);
  Serial.print(", TX Note: "); Serial.println(txNote);
}

void saveRadioKeyerModeToEEPROM(bool radioKeyerMode) {
  EEPROM.write(EEPROM_RADIO_KEYER_MODE_ADDR, radioKeyerMode ? 1 : 0);
  eeprom_commit();
  Serial.print("Saved Radio Keyer Mode to EEPROM: "); Serial.println(radioKeyerMode ? "ON" : "OFF");
}

void loadRadioKeyerModeFromEEPROM(VailAdapter& adapter) {
#ifdef HAS_RADIO_OUTPUT
  if (EEPROM.read(EEPROM_VALID_FLAG_ADDR) == EEPROM_VALID_VALUE) {
    uint8_t radioKeyerModeVal = EEPROM.read(EEPROM_RADIO_KEYER_MODE_ADDR);
    bool radioKeyerMode = (radioKeyerModeVal == 1);

    adapter.SetRadioKeyerMode(radioKeyerMode);
    Serial.print("Loaded Radio Keyer Mode from EEPROM: ");
    Serial.println(radioKeyerMode ? "ON" : "OFF");
  }
#endif
}

void loadSettingsFromEEPROM(VailAdapter& adapter) {
  if (EEPROM.read(EEPROM_VALID_FLAG_ADDR) == EEPROM_VALID_VALUE) {
    uint8_t keyerType = EEPROM.read(EEPROM_KEYER_TYPE_ADDR);
    uint16_t ditDurationVal;
    EEPROM.get(EEPROM_DIT_DURATION_ADDR, ditDurationVal);
    uint8_t txNoteVal = EEPROM.read(EEPROM_TX_NOTE_ADDR);

    Serial.print("EEPROM values - Keyer: "); Serial.print(keyerType);
    Serial.print(", Dit Duration: "); Serial.print(ditDurationVal);
    Serial.print(", TX Note: "); Serial.println(txNoteVal);

    midiEventPacket_t event;
    event.header = 0x0B; event.byte1 = 0xB0;
    event.byte2 = 1;
    event.byte3 = ditDurationVal / (2 * MILLISECOND);
    adapter.HandleMIDI(event);

    event.byte2 = 2;
    event.byte3 = txNoteVal;
    adapter.HandleMIDI(event);

    if (keyerType >= 0 && keyerType <= 9) {
      event.header = 0x0C; event.byte1 = 0xC0;
      event.byte2 = keyerType; event.byte3 = 0;
      adapter.HandleMIDI(event);
    }
  } else {
    Serial.println("EEPROM initializing with default values...");
    EEPROM.write(EEPROM_KEYER_TYPE_ADDR, 8);  // Default to Iambic B
    EEPROM.put(EEPROM_DIT_DURATION_ADDR, (uint16_t)DEFAULT_ADAPTER_DIT_DURATION_MS);
    EEPROM.write(EEPROM_TX_NOTE_ADDR, DEFAULT_TONE_NOTE);
    EEPROM.write(EEPROM_RADIO_KEYER_MODE_ADDR, 0); // Default: Radio Keyer Mode OFF
    EEPROM.write(EEPROM_VALID_FLAG_ADDR, EEPROM_VALID_VALUE);
    eeprom_commit();
    Serial.println("EEPROM initialized. Loading these defaults now.");
    loadSettingsFromEEPROM(adapter);
  }
}

// ============================================================================
// CW Memory EEPROM Functions
// ============================================================================

uint16_t getEEPROMAddressForSlot(uint8_t slotNumber) {
  // Returns the starting EEPROM address for the given slot (0-2)
  switch (slotNumber) {
    case 0: return EEPROM_MEMORY_1_ADDR;
    case 1: return EEPROM_MEMORY_2_ADDR;
    case 2: return EEPROM_MEMORY_3_ADDR;
    default: return EEPROM_MEMORY_1_ADDR;  // Safety fallback
  }
}
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

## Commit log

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2025-05-07 Fix straight key sidetone mute shortcut
    hold down key for more than 8 seconds and it will now mute on straight key. for paddles, hit the dit as fast as possible until it mutes. 10 times in a second
    [adapter.cpp]
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2025-08-18 Update adapter.h, revert for radio mode issue
    [adapter.h]
2025-08-18 Update keyers.cpp, revert for radio mode issue
    [keyers.cpp]
2025-08-18 Update adapter.cpp, revert for radio mode issue
    [adapter.cpp]
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2025-09-23 Replace dit spam counter with 5-second hold detection
    - Replace 15-press-in-500ms spam detection with continuous dit hold monitoring
    - Eliminates false positives during normal high-speed keying
    - Detection now runs in Tick() method for continuous checking vs state-change only
    - Add debug serial output showing hold timing progress
    - Works correctly with both straight key and iambic paddle operation
    - Add UF2 conversion tools (uf2conv.py, uf2families.json) for build system
    [adapter.cpp, adapter.h, config.h]
2025-09-23 Fix iambic keyer left/right control bug and add comprehensive test builds
    - Fix keyer system to properly send individual dit/dah keys instead of always left control
    - Dit paddle now sends KEY_LEFT_CTRL, dah paddle sends KEY_RIGHT_CTRL
    - Fixed ElBugKeyer pulse method to use correct relay for each element
    - Added proper relay tracking in keyer transmission logic
    - Resolved hanging issue when pressing dah paddle
    - Generated test builds for all hardware variants (V1, V1.2, V2 Advanced, No PCB)
    - Created builds for both XIAO and QT Py microcontrollers
    - Added comprehensive README for test builds with installation instructions
    Co-Authored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
    [Advanced Case Body.stl, Vail V1 PCB.kicad_pcb, Vail V1 PCB.kicad_sch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]
2025-10-02 Fix GitHub workflow deployment configuration
    - Change repository from WrathPak/vail_web_updater to Vail-CW/vail_web_updater
    - Switch from SSH deploy key to Personal Access Token authentication
    - Add correct branch reference (firmware-update-website)
    - Resolves deployment permission errors in CI/CD pipeline
2025-10-02 Switch workflow to use SSH deploy key authentication
    - Replace Personal Access Token with SSH deploy key for repository access
    - This resolves permission issues when deploying to Vail-CW organization
    - Deploy key provides secure, repository-specific access for CI/CD
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2025-10-16 example arduino files with the correct values
    example arduino files with the correct values for the 3 buttons using the WIP pcb listed in github for this
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2025-10-19 Fix keyer dit duration not restoring after radio mode release
    Restore the keyer's dit duration after releasing both radio mode
    toggle sequences to ensure the keyer timing remains correct.
    [adapter.cpp]
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2025-10-19 Rename PCB configurations and add hardware-specific button thresholds
    Configuration naming updates:
    - V1_PCB → V1_Basic_PCB
    - V1_2_PCB → V2_Basic_PCB
    - V2_ADVANCED_PCB → Advanced_PCB
    Button threshold calibration:
    - Added hardware-specific analog value thresholds in buttons.cpp
    - V2_Basic_PCB: B3=512, B2=614, B1=683, B2+3=769, B1+3=820, B1+2=830
    - Advanced_PCB: B3=280, B2=335, B1=414, B2+3=397, B1+3=490, B1+2=516
    - Different resistor tolerances between PCB revisions require separate calibration
    UF2 firmware updates:
    - Recompiled all 7 UF2 variants with new configuration names
    - Updated filenames to reflect new naming convention
    - Includes QT Py and Xiao builds for all hardware configu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
    [config.h]
2025-10-20 Fix capacitive touch squeeze detection and add button hat improvements
    Capacitive touch fixes:
    - Enhanced TouchBounce debouncing for squeeze key detection
    - Improved touch sensitivity calibration
    - Added diagnostic tools for capacitive touch threshold tuning
    Button hat updates:
    - Added HTML user guide for button hat controls
    - Removed outdated button hat test UF2s from previous PCB revisions
    - Added calibration UF2s for different resistor configurations
    Development improvements:
    - Added CLAUDE.md project documentation for AI assistance
    - Added squeeze key build test configurations
    - Added capacitive touch diagnostic firmware
    - Included vail button project documentation
    🤖 Generated with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
    [touchbounce.h, vail-adapter.ino]
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2025-10-21 Clean up branch: fix filename and remove obsolete files
    - Renamed vail-adapter 10192025.ino back to vail-adapter.ino to match master
    - Removed vail button project.md (features now implemented)
    - Removed cap touch test UF2 files (not relevant to CW memory feature)
    - Kept qtpy_advanced_pcb_memory_v6.uf2 (test firmware for this branch)
    [vail-adapter.ino]
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2025-10-26 Fix compilation errors by moving test programs to subdirectory
    Moved cap_touch_diagnostic.ino and cap_touch_test_configs.ino to test_programs/
    directory to prevent conflicts with main firmware. Arduino compiles all .ino files
    in the same directory together, causing multiple definition errors for setup(),
    loop(), and global variables. Test programs are now isolated while remaining
    available for diagnostic use.
    Updated CLAUDE.md to document project structure and explain the test_programs
    directory organization.
2025-10-26 Update CLAUDE.md to document CW memory feature and button system
    Added comprehensive documentation for:
    - CW memory recording and playback system
    - Button control and menu state machine
    - Double-click detection and gesture recognition
    - State transition guards that prevent cross-mode interference
    - Updated EEPROM storage section to include memory slots
    - Updated project structure to include memory.cpp/h
    Removed obsolete test_programs section (files deleted in merge).
2025-10-26 Redesign GitHub Pages firmware updater with modern wizard UI
    Complete overhaul of the firmware update web tool with a step-by-step wizard
    interface that simplifies the update process and improves user experience.
    - **Wizard-style interface** with 3 clear steps and visual progress indicator
    - **Step 1:** Choose model (Basic PCB, Advanced PCB, DIY No PCB) via card selection
    - **Step 2:** Choose board (QT Py or XIAO) with helpful hint about purchased adapters
    - **Step 3:** Unified flash process with all instructions in one place
    UI/UX Improvements:
    - Modern card-based selection with hover effects and animations
    - Visual progress bar showing current step and completion
    - Smooth t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
2025-10-27 Add GitHub Issue template for collaborative release testing
    This commit adds a structured release testing process using GitHub Issues:
    - Issue template with comprehensive test checklist for all firmware features
    - Tracks testing across all 8 hardware configurations (XIAO/QT Py × 4 PCB types)
    - Includes tester sign-off template for commenting with results
    - Process documentation with workflow examples and best practices
    The template covers testing for keyer modes, USB output, memory system,
    button controls, special features, and settings persistence.
2025-10-27 Update release testing template to use editable checkboxes in issue body
    Changed from copy-paste comment template to direct checkboxes in the issue:
    - All test items now in main issue body (anyone with write access can check off)
    - Organized into clear sections: Core, Keyer Modes, USB, Audio, Speed, Memory, Buttons, Special Features, Settings
    - Hardware coverage tracking at top of issue
    - Comments section for detailed bug reports and notes
    - Removed duplicate hardware coverage section
    - Fixed typos in pre-release checklist
    This makes collaborative testing easier - testers just check boxes directly
    in the issue instead of posting separate comments.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
2025-10-27 Implement two-tier testing system with hardware-specific issues
    Replaced single-issue testing approach with a scalable two-tier system:
    **New Structure:**
    - Parent "Overview" issue tracks overall release progress
    - 8 hardware-specific issues (XIAO/QT Py × 4 PCB versions) with detailed checklists
    - Each config gets isolated testing with clear ownership
    **Templates Added:**
    - release-testing-overview.md - Parent tracking issue with status summary
    - release-testing-hardware.md - Comprehensive per-hardware test checklist
    **Features:**
    - 150+ test items organized by category (keyer modes, USB, audio, memory, etc.)
    - Tester sign-off section with multiple tester support
    - Issue severity classif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
2025-10-27 Add automated GitHub Actions workflow for release testing issue creation
    Implemented one-click automation to create all 9 release testing issues:
    **New Workflow: create-release-testing-issues.yml**
    - Manual trigger via workflow_dispatch with form inputs:
    - Release version (e.g., v2.1.0)
    - Firmware build date
    - Target release date
    - What's new in this release
    - Creates 1 parent overview issue + 8 hardware-specific issues
    - Automatically links all issues together
    - Pre-fills templates with correct board/PCB/firmware info
    - Marks appropriate checkboxes for each config
    - Posts summary comment with all issue links
    - Completes in 10-30 seconds
    - Reads templates from repo (a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
2025-10-27 Add firmware building and attachment to release testing workflow
    Enhanced the automated issue creation workflow to build and attach test firmware:
    **New Firmware Build Job:**
    - Optional job that builds all 8 UF2 configs before creating issues
    - Controlled by "Build and attach firmware" checkbox (default: true)
    - Uses matrix strategy to build XIAO/QT Py × 4 PCB versions in parallel
    - Stores UF2 files as workflow artifacts (30-day retention)
    - Does NOT commit to repository - keeps test firmware private
    **Firmware Attachment:**
    - Downloads firmware artifacts after build completes
    - Posts comment on each hardware issue with firmware info:
    - Filename, version, build date, commit hash, file s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
2025-10-27 Optimize build_uf2.yml with path filters to reduce unnecessary builds
    Added path filters to only trigger firmware builds when source code changes:
    **Trigger paths (workflow RUNS):**
    - **.ino files - Arduino sketches
    - **.cpp files - C++ source code
    - **.h files - Header files
    - config.h - Hardware configuration
    - .github/workflows/build_uf2.yml - Workflow itself
    **Skip paths (workflow SKIPS):**
    - docs/ - Website, documentation, PDFs
    - Markdown files (README.md, CLAUDE.md, etc.)
    - .github/ISSUE_TEMPLATE/ - Issue templates
    - 3dprints/, pcb/ - Hardware design files
    - Other non-code changes
    **Benefits:**
    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
2025-10-27 Improve Vail Summit web flasher UX and functionality
    Major improvements to ESP32 web flasher:
    - Implemented two-step bootloader entry process (no BOOT button required)
    - Fixed firmware binary data conversion for proper flashing
    - Disabled MD5 verification to avoid false failures
    - Added dark mode styling for flash log
    - Updated device icons (📡 for Adapter, ⛰️ for Summit)
    - Improved error handling and user instructions
    - Added automatic hardware reset attempt after flashing
    - Updated instructions to unplug/replug after flash
    Technical fixes:
    - Convert firmware files to binary string format for esptool-js
    - Properly close and forget ports between steps
    - Initialize ESP flasher when nav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
2025-10-27 Add GitHub Actions workflow for building Summit firmware
    This workflow allows manually building and deploying Vail Summit firmware
    from any branch to the master branch firmware directory.
    - Manual trigger via workflow_dispatch
    - Configurable source branch (default: vail-summit)
    - Builds firmware using Arduino CLI for ESP32-S3 Feather
    - Automatically switches to master branch after build
    - Copies .bin files to docs/firmware_files/summit/
    - Commits and pushes to master (with [skip ci] to avoid loops)
    - Uploads build artifacts for 30-day retention
    Usage:
    1. Go to Actions tab on GitHub
    2. Select "Build and Deploy Summit Firmware"
    3. Click "Run workflow"
    4. Enter source branch name (e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
2025-10-30 Fix Summit web flasher for ESP32-S3 TinyUSB compatibility
    Updates the GitHub Pages updater tool to work with ESP32-S3's TinyUSB upload mode by implementing the same 1200-baud reset process used by Arduino IDE.
    - esp-flasher.js: Add automatic port detection after bootloader reset
    - esp-flasher.js: Implement 1200-bps touch reset (like Arduino IDE)
    - esp-flasher.js: Auto-detect new bootloader port instead of manual selection
    - index.html: Simplify UI from two-step to streamlined bootloader flow
    - SUMMIT_INTEGRATION.md: Update documentation with new process details
    - Add build_all.sh script for local firmware compilation
    - Remove obsolete user guide files and old UF2 firmware
    - Update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
    [adapter.cpp, menu_handler.cpp, morse_audio.cpp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]
2025-11-05 Improve button detection and fix ElBug keyer queue handling
    - Refined button threshold ranges for B1+B2 (826-835) and B1+B3 (815-821) combos for more reliable detection
    - Fixed ElBug keyer to properly discard queued dits when paddle released before transmission
    - Updated GitHub Pages updater to reflect latest changes
    [keyers.cpp]
2025-11-06 Revert Ultimatic keyer regression from commit 15a6615
    - Restore original Ultimatic keyer logic that was working correctly
    - Remove paddle-still-pressed check that was incorrectly applied from ElBug fix
    - The November 4th commit mistakenly applied ElBug queue handling logic to Ultimatic mode
    - Ultimatic mode now functions properly again with its simpler queue behavior
    - Update GitHub Pages updater to reflect this bug fix
    [keyers.cpp]
2025-11-08 Add button hat troubleshooting tool with XIAO and QT Py support
    Added diagnostic tool to help troubleshoot button hat PCB issues by measuring
    analog values from the resistor ladder network.
    - Interactive serial prompt guides user through testing all 7 button states
    - 50 samples per test with min/max/average reporting
    - Automatic status checking against expected ranges
    - Pre-compiled UF2 files for both QT Py and XIAO SAMD21
    - Comprehensive documentation with troubleshooting tips
    Files added:
    - button_troubleshoot/button_troubleshoot.ino - Main diagnostic sketch
    - button_troubleshoot/button_test_qtpy.uf2 - QT Py firmware
    - button_troubleshoot/button_test_xiao.uf2 - XIAO firmware
    -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
    [button_troubleshoot.ino]
2025-11-12 Fix stuck Control key issue on USB disconnect/mode change
    Resolves issue where LEFT_CTRL or RIGHT_CTRL keys would remain stuck
    after unplugging the adapter or during state transitions, preventing
    normal keyboard input until keys were manually spammed or adapter
    unplugged.
    - Add ditKeyPressed/dahKeyPressed state tracking in VailAdapter class
    - Modify keyboardKey() to track when keys are pressed/released
    - Update Tx() to only release keys that were actually pressed
    - Add ReleaseAllKeys() safety method to ensure clean state
    - Call ReleaseAllKeys() on startup and during critical transitions:
    * Device startup (vail-adapter.ino)
    * Radio mode toggle
    * Radio keyer mode toggle
    * Key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
    [adapter.cpp, adapter.h, vail-adapter.ino]
2025-11-12 Improve CW memory recording and Advanced PCB button calibration
    CW Memory Enhancements:
    - Add paddle info (DIT/DAH) encoding to memory transitions
    - Store paddle flag in bit 15 of each transition uint16_t
    - Update ENCODE_TRANSITION/DECODE_DURATION/DECODE_PADDLE macros
    - Enable proper playback with correct paddle routing for radio mode
    - Fix recording to capture which paddle was pressed (not just timing)
    - Add currentPaddle tracking to RecordingState
    - Update memory playback to pass paddle info to BeginTx()/EndTx()
    Advanced PCB Improvements:
    - Update button pin mapping for wire mod (pin 3 → pin 8)
    - Comment out QT_KEY_PIN A8 (conflicts with button on A8)
    - Recalibrate button thresholds for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
    [button_troubleshoot.ino, config.h, memory.cpp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]
2025-11-12 Add button hat modification guide to GitHub Pages
    Firmware dated November 11, 2025 or later requires a hardware
    modification for Advanced PCB with button hat installations due to
    button pin remapping (A4 → A8) to avoid radio output conflicts.
    - Add prominent warning banner to index.html firmware updater
    - Create comprehensive button-hat-mod.html guide page with:
    * Step-by-step modification instructions
    * Materials list and skill level requirements
    * Pin diagram reference section
    * Detailed soldering procedures
    * Testing and troubleshooting sections
    * Contact information (ke9bois@pigelradio.org, Discord)
    - Create docs/images/ directory with README for image uploads
    - U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
2025-11-12 Fix image filenames in button hat modification guide
    Update image references to match actual uploaded files:
    - diagram.png (Arduino pin diagram)
    - 1.jpg (modification example photo 1)
    - 2.jpg (modification example photo 2)
2025-11-12 Update button hat modification guide with final corrections
    - Clarify modification only applies to Vail Adapter (not Summit)
    - Specify only button hats purchased in 2025 need modification
    - Note that 2026+ button hats will use updated PCBs
    - Update config.h for V2_Basic_PCB to use BUTTON_PIN 8 (A8)
    [config.h]
2025-11-18 Add Vail Lite (TRRS Trinkey) support and update firmware updater
    - Add TRRS Trinkey hardware configuration to config.h
    - Add Trinkey build target to GitHub Actions workflow (9 total variants now)
    - Update GitHub Pages firmware updater with Vail Lite option
    - Vail Lite skips board selection step (only one hardware variant)
    - Update "What's New" section with Trinkey support and limitations
    - Add TRRS_TRINKEY_BUILD.md documentation
    - Include pre-built trinkey_vail_adapter.uf2 firmware
    - Update button troubleshoot files and R2R continuous read sketch
    [config.h, keyers.cpp, morse_audio.cpp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]
2025-11-18 Update firmware builds and fix Trinkey FQBN
    - Fix Trinkey FQBN: adafruit_trinkey_m0 → adafruit_TRRStrinkey_m0
    - Update build_all.sh to support Trinkey builds (9 total variants)
    - Build and include all 9 firmware UF2 files in docs/firmware_files/
    - Update GitHub Actions workflow with correct Trinkey FQBN
    All firmware variants:
    - XIAO: basic v1/v2, advanced, non-pcb (4 files)
    - QT Py: basic v1/v2, advanced, non-pcb (4 files)
    - Trinkey: vail_adapter (1 file)
    [config.h]
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2026-01-22 Improve Summit web flasher for USB connection issues
    - Make manual bootloader entry (BOOT+RESET) the primary method
    - Add "Full Erase & Flash" option to clear stale USB config data
    - Add alternative reset methods (DTR/RTS, Direct Connect)
    - Improve error messages with specific troubleshooting guidance
    - Add button group styling and highlight animations
    - Update troubleshooting section with TinyUSB CDC solutions
    - Hide auto-reset options in collapsible section (unreliable with TinyUSB)
    This helps users whose devices show as "TinyUSB CDC" instead of
    "USB JTAG/Serial" and have persistent connection issues.
2026-01-22 Simplify Summit flasher UI: automatic method primary, manual fallback
    - Main button now "Connect & Flash Summit" - does automatic bootloader entry
    plus connect and flash in one streamlined flow
    - Manual bootloader instructions moved to collapsible fallback section
    - Fallback automatically expands when automatic method fails
    - Removed intermediate buttons (Alternative Reset, Manual Bootloader Confirm)
    - Simplified troubleshooting section
    - Removed unused button handlers from JavaScript
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2026-01-22 Make What's New section device-specific
    - Hide section on initial device selection page
    - Show vail-adapter commits when Adapter is selected
    - Show vail-summit commits when Summit is selected
    - Hide manual link for Summit (doesn't have one)
    - Hide section when navigating back to step 1
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2026-02-07 Fix CORS error when downloading Summit firmware from releases
    GitHub release browser_download_url goes through github.com which
    lacks CORS headers. Switch to using the GitHub API asset URL
    (api.github.com) with Accept: application/octet-stream header,
    which redirects to a CORS-enabled CDN.
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2026-04-22 updater: add WebSerial AVR109 flasher, Arduino Micro flow, and opt-in test channel
    Three intertwined updates to the live site at vailadapter.com:
    1. WebSerial AVR109 / Caterina flasher
    - New docs/avr109-flasher.js: vendored Intel HEX parser + AVR109
    protocol + 1200-baud bootloader touch. No WASM dependency.
    - Exposes window.AVR109Flasher and window.avr109Touch1200.
    2. Arduino Micro flow
    - New "Arduino Micro" card in Step 2 (hidden unless test channel
    is active — see below).
    - New step3_micro section: plug in -> 1200-baud touch -> select
    bootloader port -> flash -> finalize. Progress bar and flash log
    included. Troubleshooting for port-picking mistakes and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
2026-04-22 ci-fix: remove unused SECOND macro that collides with FreeTouch headers
    The #define SECOND (1000 * MILLISECOND) in config.h has been dead code
    the whole time — no source file references SECOND. Meanwhile something
    in the modern Adafruit FreeTouch dependency chain now defines SECOND
    (likely an enum member in an ASF/CMSIS RTC header), and the macro
    redefinition breaks compilation of any config that pulls FreeTouch in.
    This has silently broken master's CI for all 8 SAMD21 variants since
    November 2025; only TRRS Trinkey and Arduino Micro (both NO_CAPACITIVE_TOUCH)
    have been building.
    Just drop the unused macro. MILLISECOND is still defined and used.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
    [config.h]
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2026-05-10 summit firmware: add test-channel deploy + use bundled arduino-cli env
    Rewrites build_summit_firmware.yml to bring it in line with the rest
    of the firmware tooling:
    1. Adds deploy_target input (test / stable / none) mirroring the UF2
    workflow. 'test' deploys to docs/firmware_files/test/summit/ so
    the live updater's 🧪 Test channel can fetch beta Summit builds
    exactly the same way it already does for Adapter UF2 firmware.
    The vail-adapter docs/script.js firmwareUrl() prefix swap will
    pick this up automatically once the directory exists.
    2. Switches from generic Arduino CLI + ad-hoc 'lib install' calls to
    the bundled, pinned environment in vail-summit/arduino-cli/. This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
2026-06-11 Reorganize hardware files under hardware/ by variant
    Group the PCB designs and printable cases into one hardware/ folder,
    organized by adapter variant so each board and its case sit together:
    - hardware/basic-adapter/{pcb,case}
    - hardware/advanced-adapter/{pcb,case}
    - hardware/button-hat/pcb
    Flatten the redundant button-hat directory nesting, drop the empty
    placeholder readmes, and move the r2r_* button-hat test sketches (Arduino
    firmware, not board design) into tools/. Add hardware/README.md and a
    pointer to it from the main README. Replaces the old pcb/ and 3dprints/
    top-level folders.
    [Advanced Case Body.stl, Advanced_W_Button_Cap.stl.stl, Advanced_W_Button_Case.stl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]
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2026-06-12 Add Troubleshooting Recorder to updater
    Device-agnostic serial log capture page (troubleshoot.html): user picks
    their device, baud is mapped automatically (Adapter 9600, Summit 115200),
    captures serial output to save and share for debugging. Adapter path adds
    an unplug/replug 'Capture Startup' mode that latches onto the port the
    instant it re-enumerates; Summit uses an ESP reset-over-wire restart.
    [troubleshoot.js]
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
